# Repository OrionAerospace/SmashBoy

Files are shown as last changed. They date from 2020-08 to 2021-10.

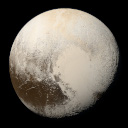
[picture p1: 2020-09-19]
Telemetria/Software/RPi/pluto128.jpg

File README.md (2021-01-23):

# SmashBoy

[Lista de componentes](https://docs.google.com/spreadsheets/d/1D1GIcy4P2cfkP9AKwlNsk9UkS25Sl03CtQvyfefxdTE/edit#gid=0)

[Posição Pinos Conector](https://docs.google.com/spreadsheets/d/1PznWzXu9q9Dlj_FaWwlBaMU61vmlcZUDXJRLBAa3UJ4/edit#gid=0)

LAYERS SMASHBOY

(9) --> 

(8) --> Controle

(7) --> 

(6) --> Atuadores Controle

(5) -->

(4) --> Bateria  (ok)

(3) --> Controlador bateria  (ok)

(2) --> Transceiver  (ok)

(1) --> Câmera + OBC & PYLD Ctrl  (ok)

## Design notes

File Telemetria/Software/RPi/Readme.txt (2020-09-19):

19/09/2020

Transferencia de arquivos por SPI com CRC32 e cabeçalho foi implementada
Falta ainda implementar a lógica com UART e o tratamento de erros

O ARQUIVO DEVE SER COMPILADO COM PYTHON 3

-------------------------------------

16/09/2020

Criada a pasta RPi, aqui estará todo o código para o Raspberry.

Em maio eu havia escrito um código em C, mas como a câmera funciona com um código em Python, então acho que não haverá uma mudança
 significativa de desempenho se todo o algoritmo do raspberry for em Python. Além disso, em Python fica mais simples para ser lido
 pelas próximas pessoas que estarão fazendo parte da equipe.

--------------------------------------

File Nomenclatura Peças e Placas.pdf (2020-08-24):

# Padronização Nomenclatura Peças e Placas

## Description

Padronizar o nome e caminho para fácil localização e entendimento.

PADRÃO NOMENCLATURA (EX):

SMASHBOY_AVI_ACI_ASS01_PART01_V01

Leitura: Projeto SmashBoy, Área da Aviônica, Equipe de Acionamentos e Estrutura, Montagem de Peças, Peça 01, Versão 01.

Sendo os espaçamentos (em ordem):

1. Nome do projeto.
2. Área.
3. Equipe.
4. Montagem de peças ou placas.
5. Peça ou Placa.
6. Versão.

OBS:

- O espaçamento 3 pode ser preenchido com os respectivos códigos: ACI (acionamento e estrutura), ENE (energia), CON (controle), TEL (telemetria).
- Para CAD em SolidWorks o espaçamento 4 = ASS (assembly).
- Para CAD em Altium o espaçamento 4 = PCB (printed circuit board).
- Para casos que tenham integração Altium + SolidWorks, espaçamento 4 = INT (integração).

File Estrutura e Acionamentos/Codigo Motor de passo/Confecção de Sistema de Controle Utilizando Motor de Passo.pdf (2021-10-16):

Confecção de Sistema de Controle Utilizando Motor de Passo

Para o desenvolvimento do projeto, o qual tem como objetivo se mover em linha reta com velocidade constante de 5 cm/s, será utilizado motor de passo e sensor de fim de curso.

Materiais Utilizados

- 1 Esp 32 ou Arduíno;
- 2 Chaves Fim de Curso;
- 1 Motor de Passo;
- 2 Led’s (verde e azul);
- Fonte de alimentação 9V - 500mA;
- 2 Resistores (150Ω);
- 1 Capacitor eletrolítico (100µF);
- Driver Motor de Passo A4988;

Código

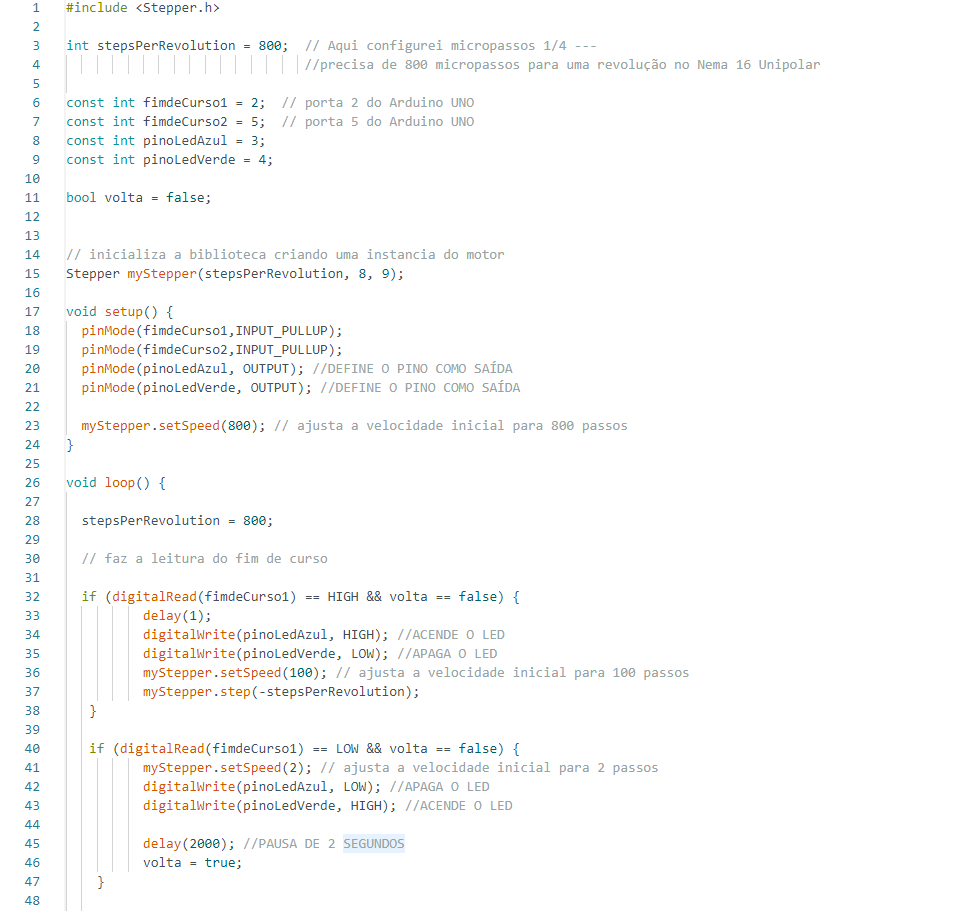
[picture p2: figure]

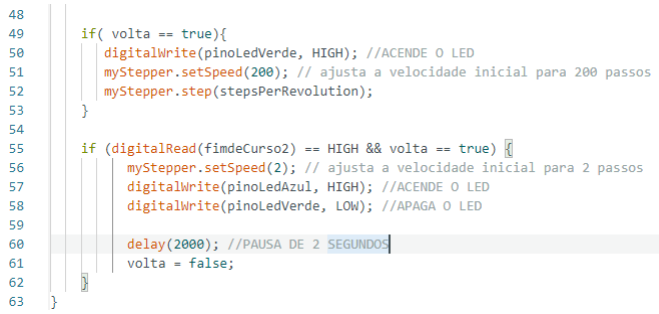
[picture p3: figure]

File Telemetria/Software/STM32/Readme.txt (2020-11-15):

11/2020

Todo o sistema passou por uma grande mudança, todo o código foi reescrito e toda sua lógica reformulada.

'Fluxograma RTOS V3' trás uma reestruturação das tasks, onde agora apenas uma única task pode acessar o 
 módulo de rádio, isso reduziu drasticamente a complexidade além da redução de memória e probabilidade
 de falhas/erros.
 
Outra grande mudança foi a lógica de "Maquina de estados" que simplificou drasticamente a programação e
 tornou o código mais simples de entender e mais seguro.

-----------------------------------------------------------
09/2020

[DESATUALIZADO] SmashBoy - FreeRTOS - Funcionamento Superficial Software [DESATUALIZADO] 
https://docs.google.com/spreadsheets/d/1H0UxWHC4-2a8tMSLyNS2wVXkgVRTFNAkbJkslC1BT0Q/edit#gid=0

[DESATUALIZADO][DESATUALIZADO]
O fluxograma RTOS V1 descreve a maneira como o sistema operacional do CubeSat irá se comportar, cada Task 
 pode ser compreendida como um conjunto de instruções que funciona em seu próprio loop de trabalho, 
 algumas tasks possuem dependências com outras.

[DESATUALIZADO] [DESATUALIZADO] [DESATUALIZADO] 
O rádio se encontrará na maior parte do tempo em RX mode, assim que uma nova mensagem chegar, será 
 encaminhada para a Task 0 (que estará ativa durante todo o tempo) esta task é responsável por fazer 
 uma triagem da informação e ativar a task que corresponde à tarefa, além disso, assim que uma mensagem 
 for recebida com sucesso, um ACK será emitido, informando para a base que o CubeSat recebeu o comando 
 com sucesso. A task 1 é responsável por concentrar toda a informação e envia-la ao transmissor 
 periodicamente. A task 2 é responsável por realizar o envio da imagem e é a única que não depende da 
 task 1 para o envio dos dados, a imagem será enviada assim que o comando for recebido. As demais tasks 
 são autoexplicativas.
 [DESATUALIZADO] [DESATUALIZADO] [DESATUALIZADO]

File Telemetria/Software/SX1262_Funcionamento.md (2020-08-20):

# SX1262

---------------------------

### Notas sobre o funcionamento do SX1262 e SX1280.

Henrique Terzi Lucchetta, 20/08/2020.

----------------------------

Este CI não necessita de biblioteca, pois o mesmo já implementa uma sequência de funcionamento semelhante ao uso de uma. É fundamental monitorar o pino BUSY, pois com base no nivel lógico deste pino que será possível determinar quando o CI está apto para receber um novo comando, caso este pino não seja monitorado, ocorrerão falhas inesperadas de funcionamento.

A interpretação do datasheet é confusa num primeiro momento, diferentemente de sua versão anterior (SX1272) este CI não fornece a tabela completa de registradores, então sua configuração e uso acontece por meio de "funções" baseadas em OpCode.

A seção 14 do datasheet explica a sequência de funcionamento para uma transmissão e para a recepção. Cada item descrito na seção 14 tem seu funcionamento descrito na seção 13, cada função da seção 13 possui um OpCode, esse OpCode é sempre o primeiro byte que vai informar para o CI o que os dados seguintes representam, exemplo:

**SetStandby**, coloca o CI em Standby e define qual o oscilador interno será utilizado durante este modo (RC ou XTAL), a mensagem que será transmitida deve primeiramente verificar se o pino BUSY está em LOW, caso esteja em HIGH aguarde passar para LOW, em seguida o pino SPI NSS deve ir para LOW para o SX1262 receber o comando, depois deve enviar o OpCode correspondente a SetStandby (no caso, 0x80) e o próximo byte correspondente ao oscilador utilizado (StdbyConfig), neste caso pode ser (0x00 ou 0x01), a mensagem completa enviada via SPI será então **0x80 0x00** ou **0x80 0x01**.

Read/WriteRegister e Read/WriteBuffer, também possuem OpCodes, endereços e offsets que devem ser enviados antes do valor a ser lido ou inserido nos registradores, exemplo WriteRegister:

 > BUSY == LOW
 
 > NSS = LOW
 
 > SPI_WRITE = **0x0D 0x07 0x40 0x34 0x44**
 
 > NSS = HIGH
 
 No caso da mensagem acima, foi atribuido no registrador 0x0740 o valor 0x34 e no 0x0741 o valor 0x44, a cada novo byte o endereço seguinte é automaticamente definido.
 
 **Além de aguardar o pino BUSY, é necessário tbm aguardar um breve periodo de tempo para enviar o próximo comando, este tempo é especificado no datasheet**

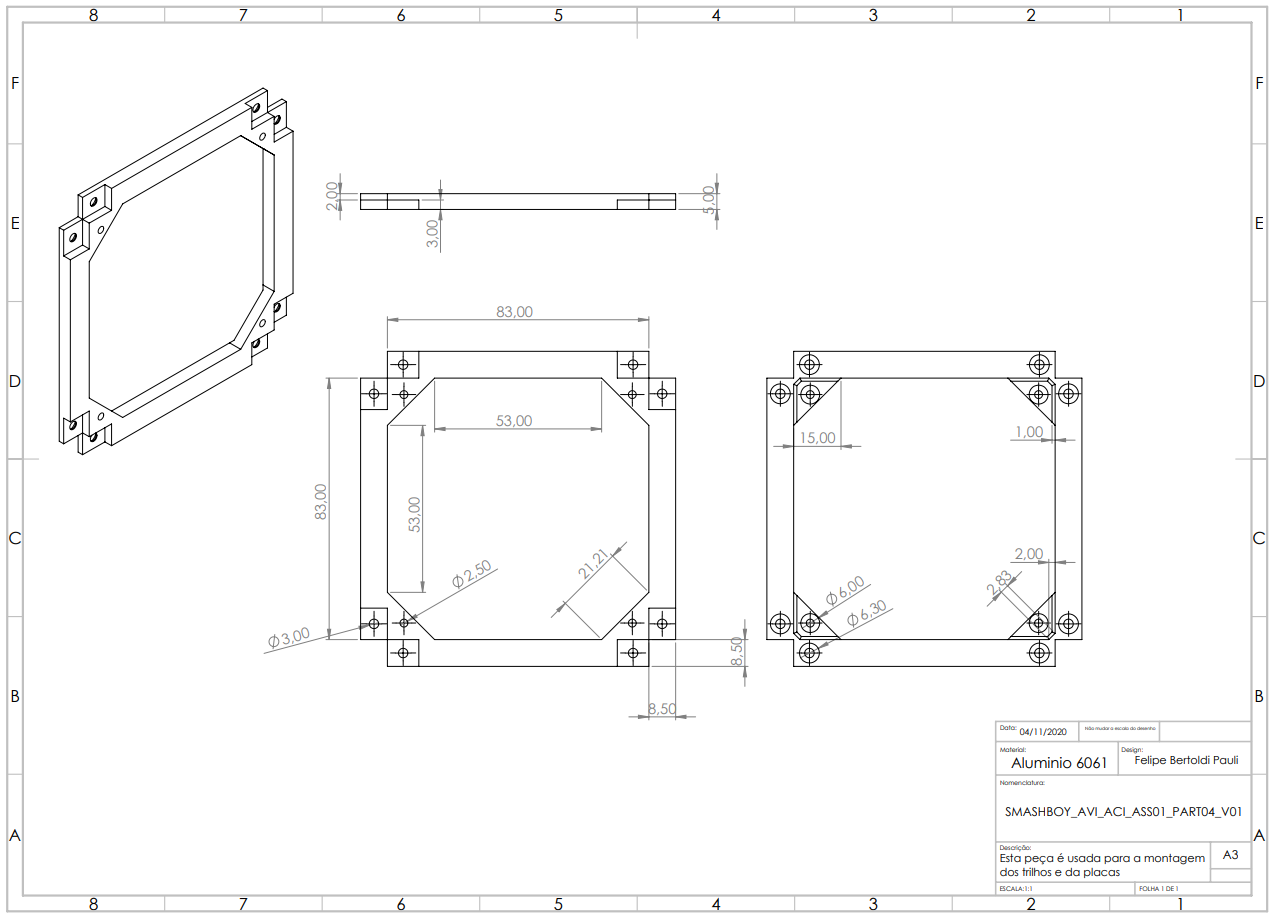
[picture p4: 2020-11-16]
Estrutura e Acionamentos/peça esqueleto/Capturar.PNG

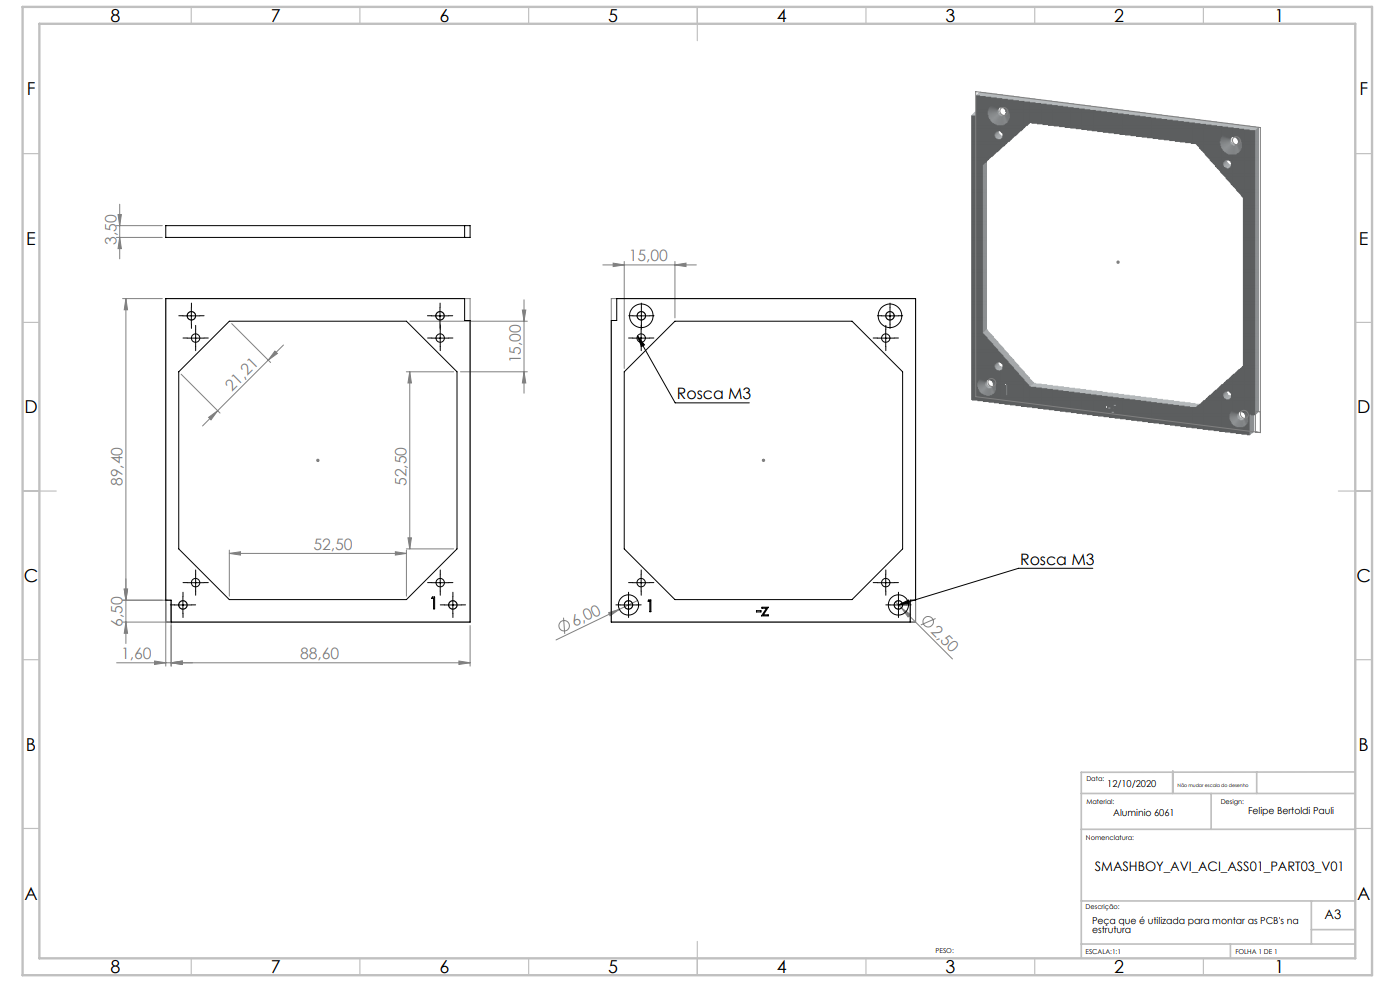
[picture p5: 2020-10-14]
Estrutura e Acionamentos/Fixação das placas/Capturar.PNG

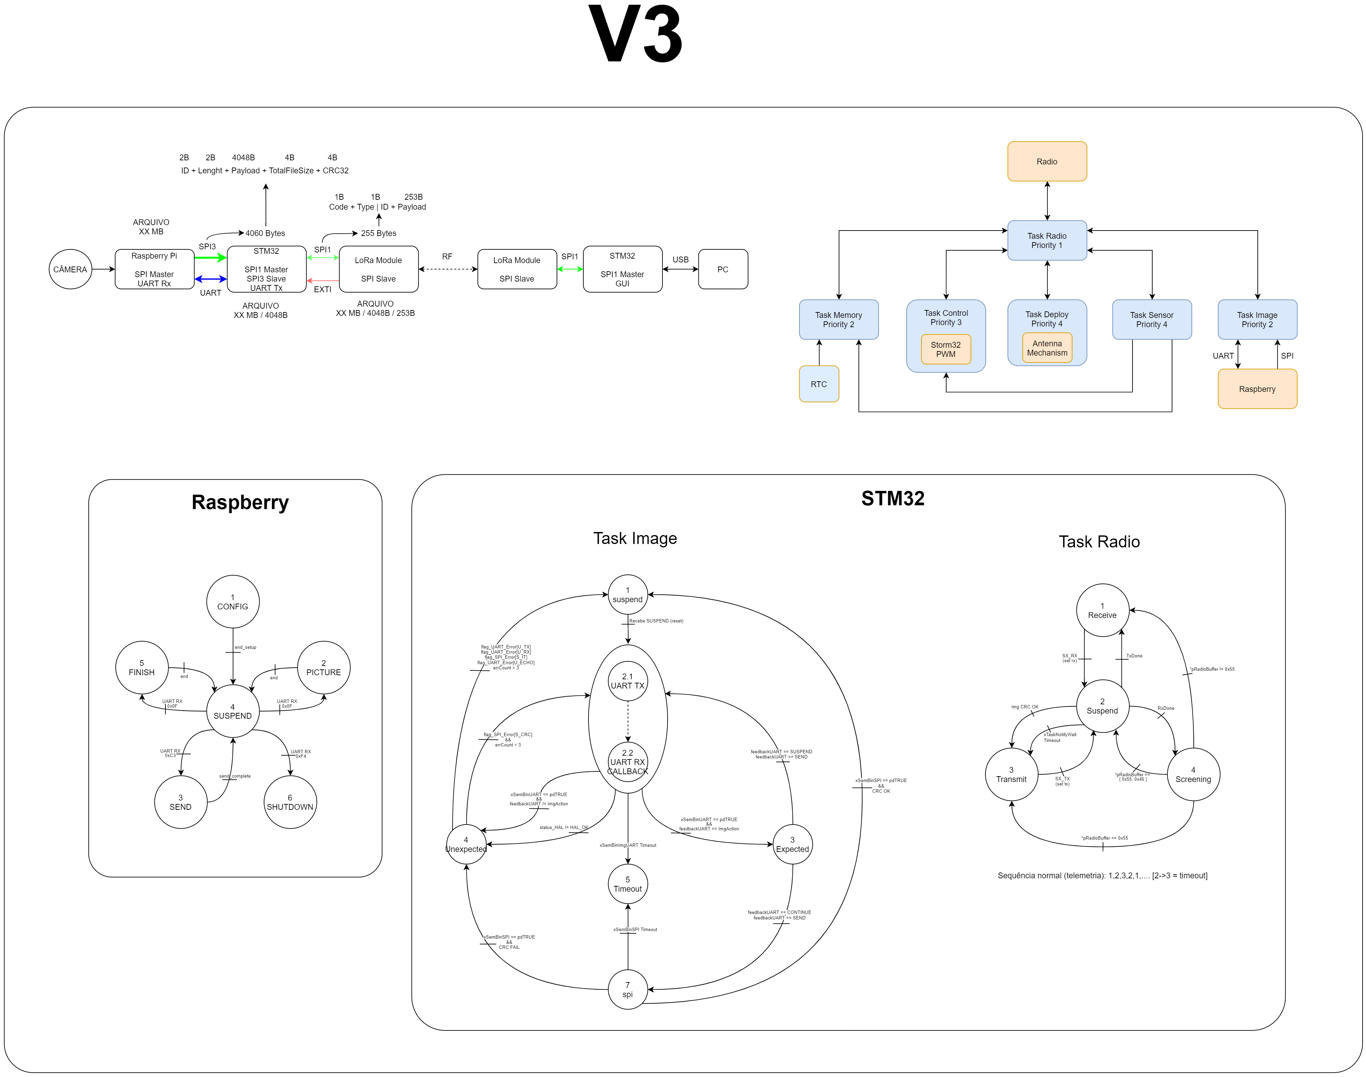
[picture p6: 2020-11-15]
Telemetria/Software/STM32/Software_SmashBoy_V3.png

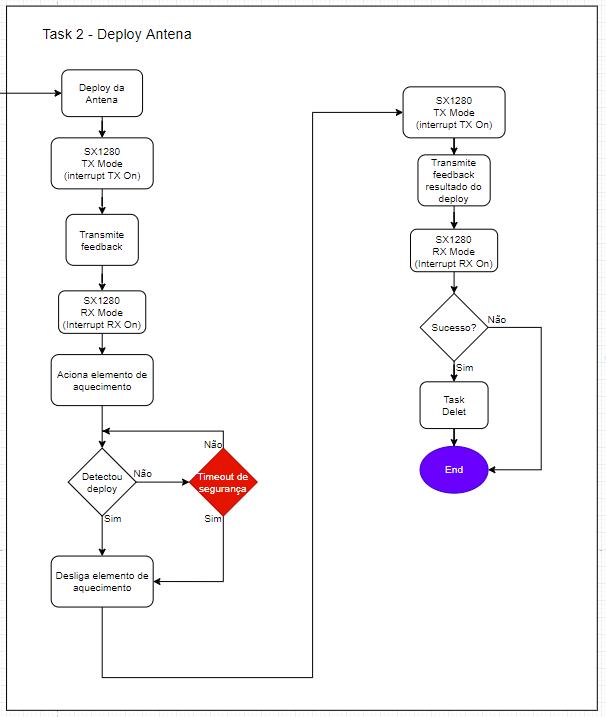
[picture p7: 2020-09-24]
Telemetria/Software/STM32/fluxograma RTOS - Deploy [ DESATUALIZADO ].png

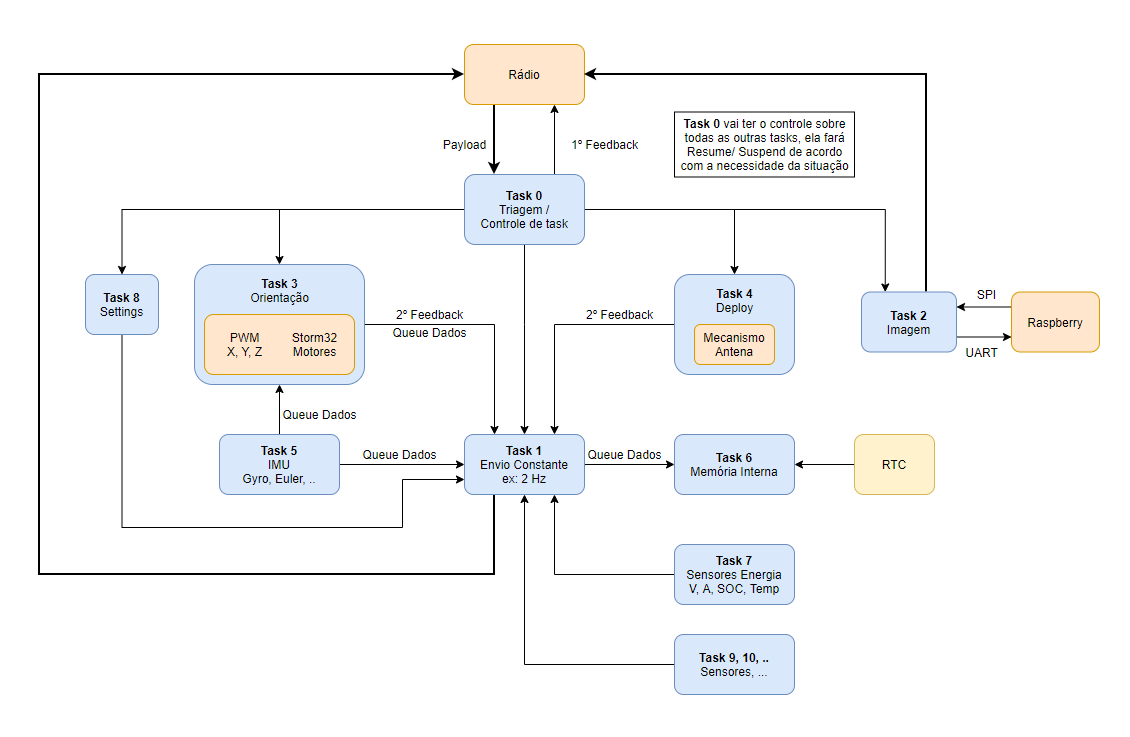
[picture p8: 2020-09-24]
Telemetria/Software/STM32/fluxograma RTOS V1.png

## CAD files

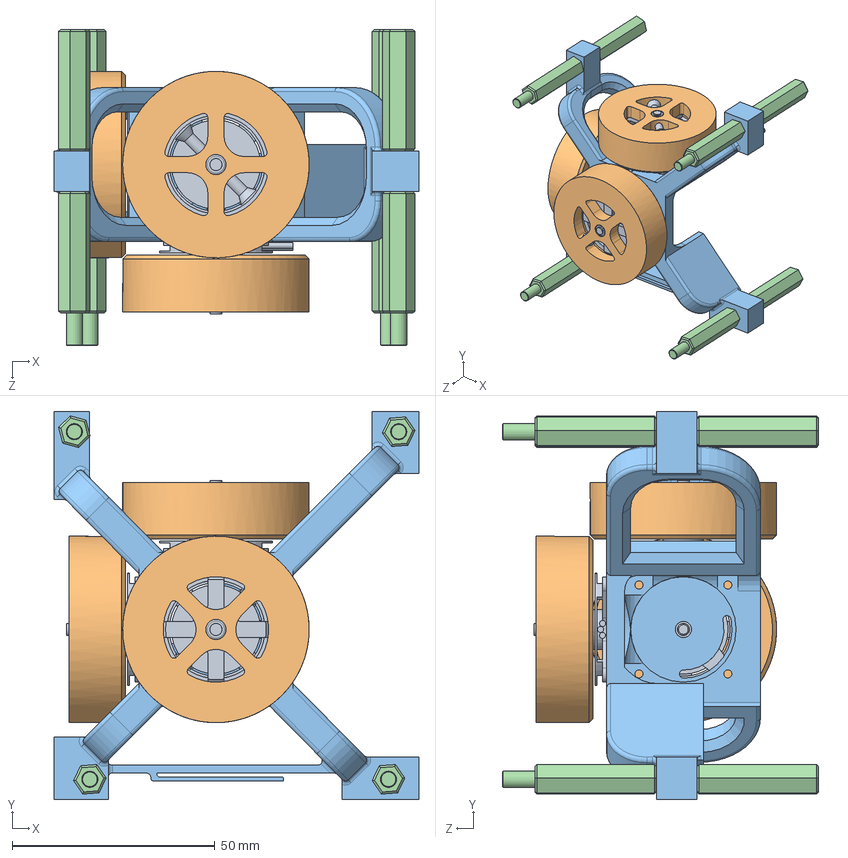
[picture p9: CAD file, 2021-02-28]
Estrutura e Acionamentos/Roda de reação/Roda_reação.SLDASM
90.0 x 95.7 x 78.0 mm
LE2204 kv1800 x 3
roda de reação x 3
suporte
Espaçador-30mm (971300474) x 8

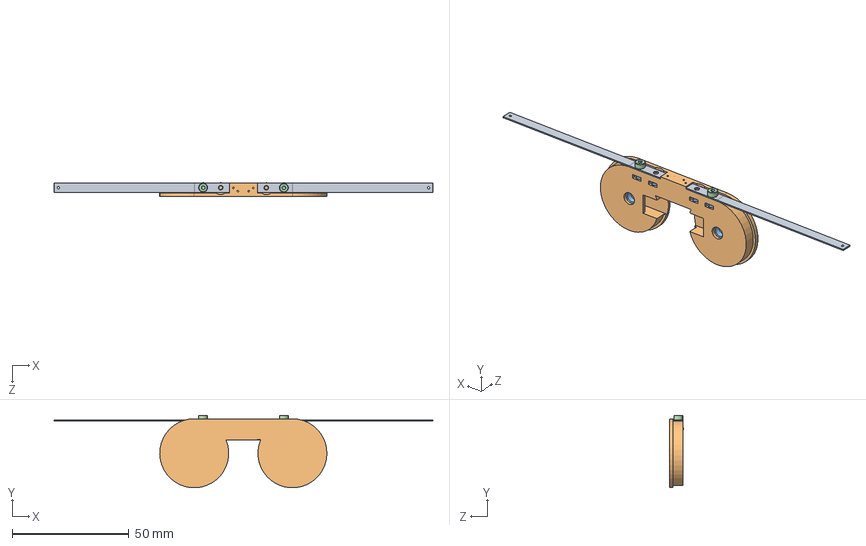
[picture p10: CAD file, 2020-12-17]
Estrutura e Acionamentos/base deploy/dedede.SLDASM
162.1 x 31.0 x 6.19 mm
antena_01 x 2
base deploy^dedede
hex thin nut chamfered gradeab_din x 6
socket head cap screw 4762_din x 2

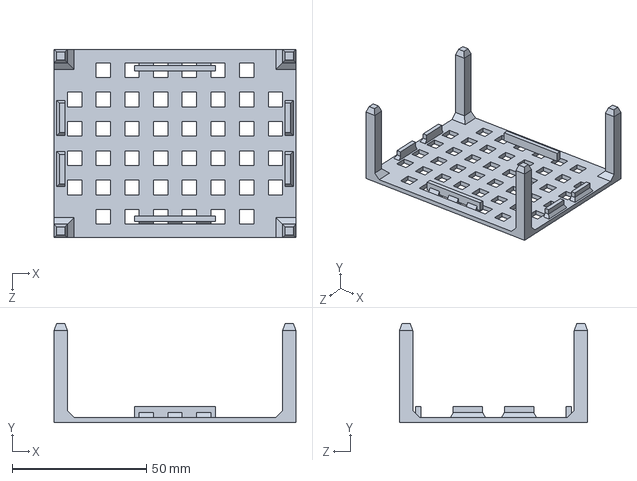
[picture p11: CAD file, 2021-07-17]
ADCS/SETUP_ADCS/antigo/L1.SLDPRT
90.0 x 37.0 x 70.0 mm

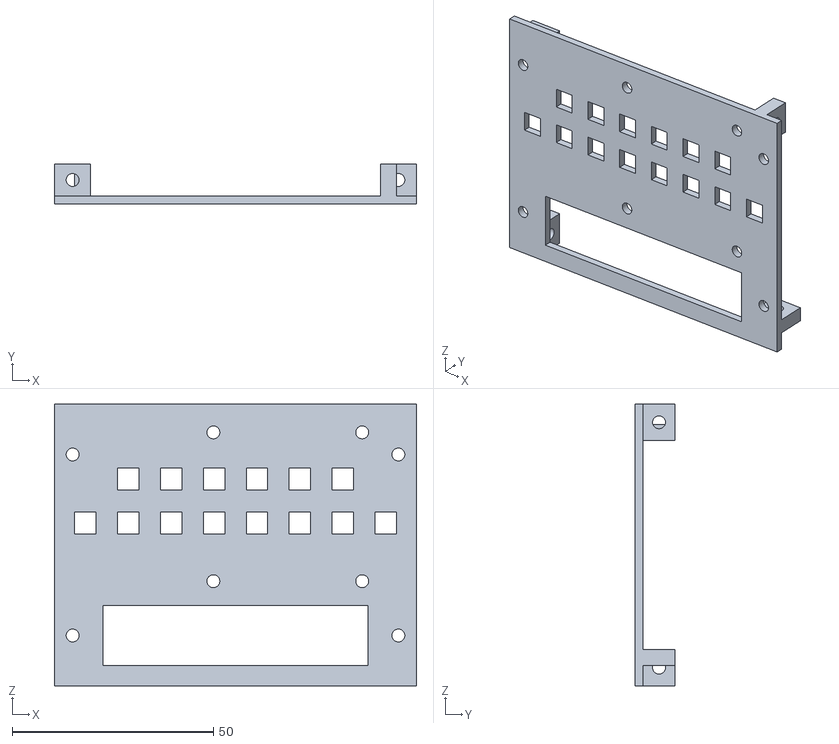
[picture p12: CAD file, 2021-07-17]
ADCS/SETUP_ADCS/STL/L2_v2.STL
90.0 x 10.0 x 70.0

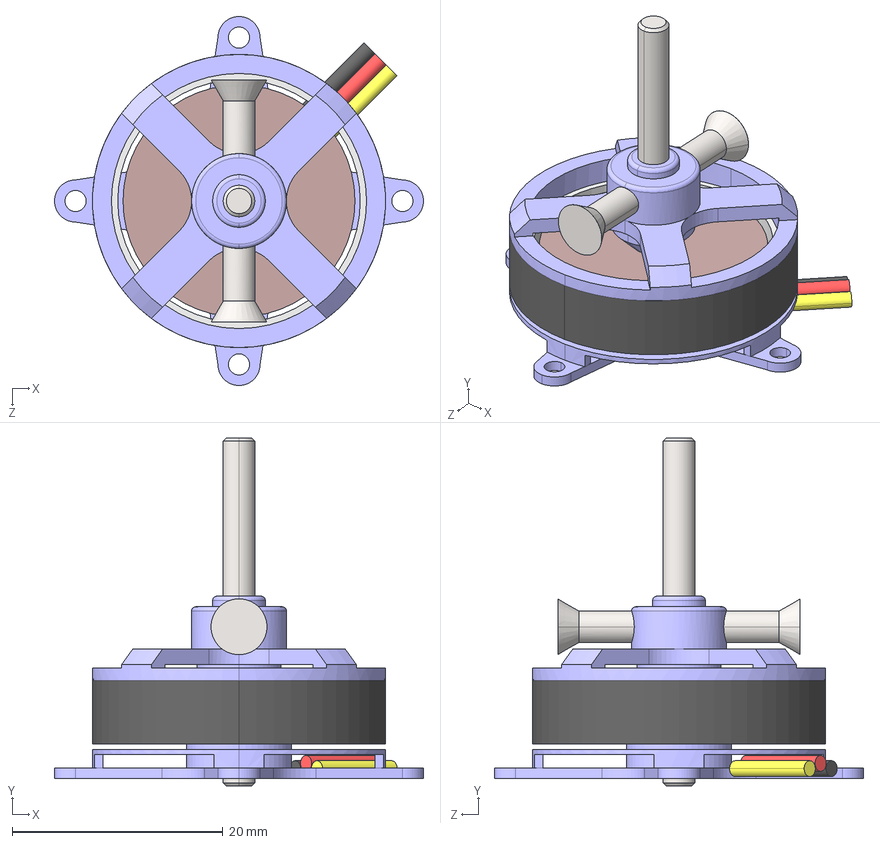
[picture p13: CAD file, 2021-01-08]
Controle/Motor_BLDC_LE2204_KV1800.STEP
35.0 x 33.0 x 35.0 mm

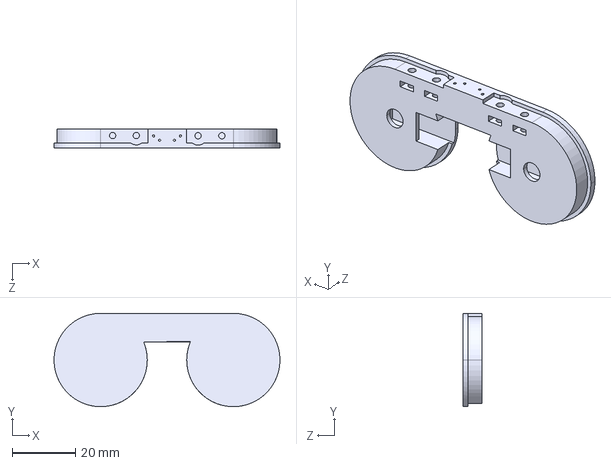
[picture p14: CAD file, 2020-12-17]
Estrutura e Acionamentos/base deploy/SMASHBOY_AVI_ACI_ASS01_PART05_V01..STEP
71.5 x 29.5 x 5.90 mm

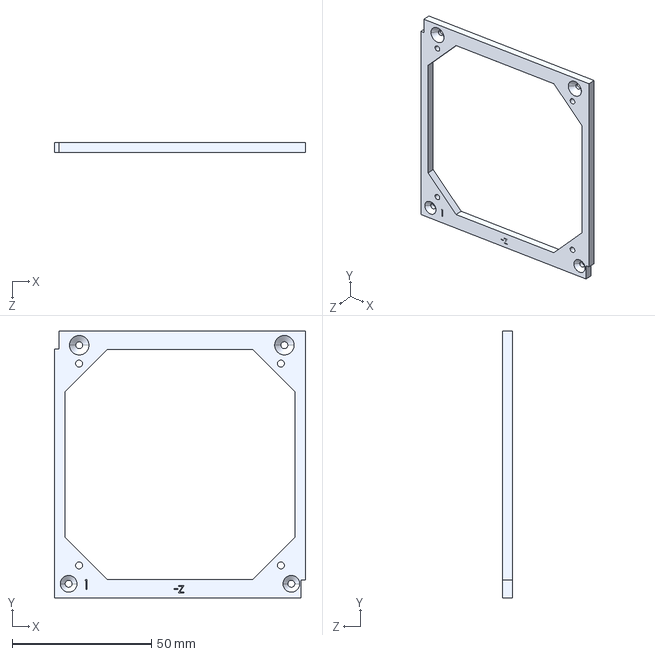
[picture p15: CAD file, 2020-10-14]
Estrutura e Acionamentos/Fixação das placas/fixação placas -face -z.STEP
90.2 x 95.9 x 3.50 mm

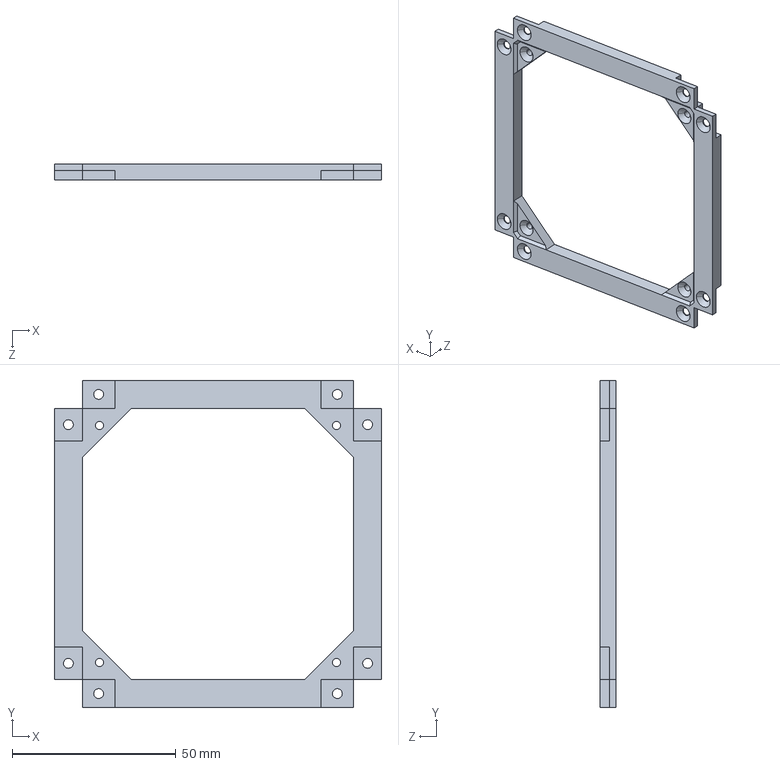
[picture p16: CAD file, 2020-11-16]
Estrutura e Acionamentos/peça esqueleto/peça esqueleto-v2.STEP
100.0 x 100.0 x 5.00 mm

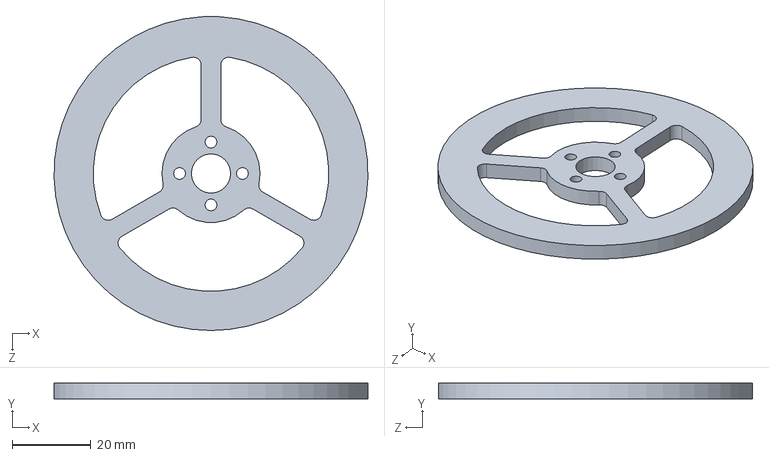
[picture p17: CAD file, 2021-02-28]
Estrutura e Acionamentos/Roda de reação/[3D]_SMASHBOY_Layers_Motor_Disco/Peça2.SLDPRT
80.0 x 4.00 x 80.0 mm

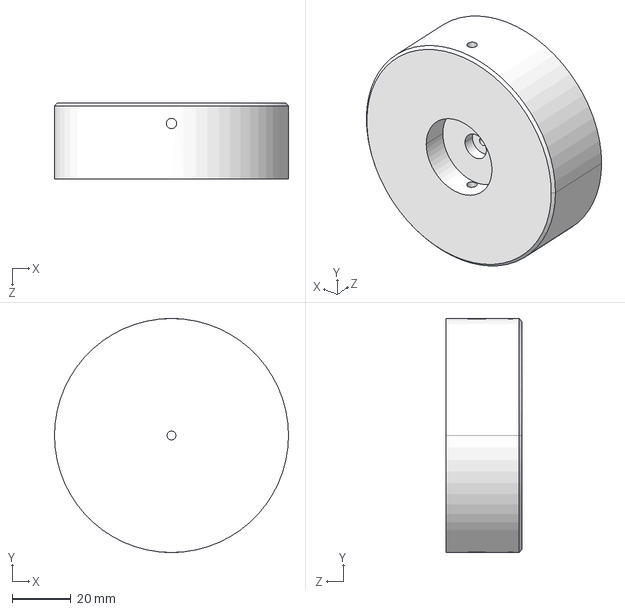
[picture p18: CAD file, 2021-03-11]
Estrutura e Acionamentos/Roda de reação/massa/roda de reação_nylon.STEP
80.0 x 80.0 x 26.0 mm

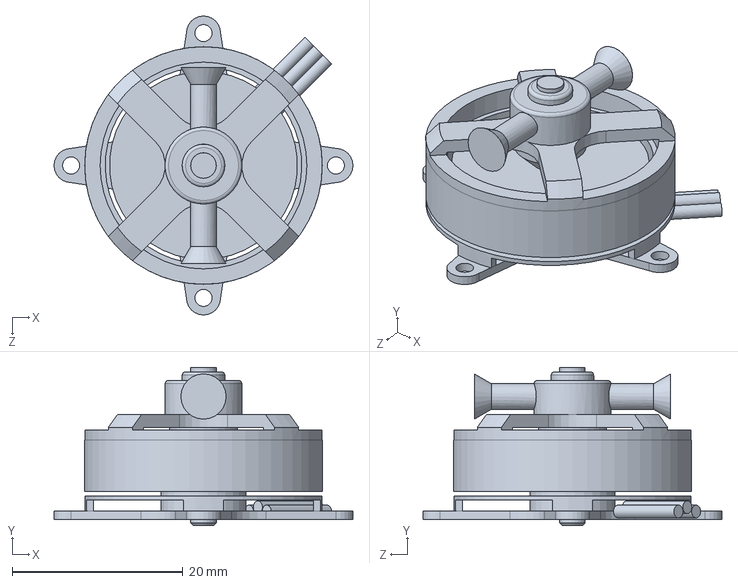
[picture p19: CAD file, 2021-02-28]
Estrutura e Acionamentos/Roda de reação/motor/LE2204 kv1800.SLDPRT
35.0 x 18.5 x 35.0 mm

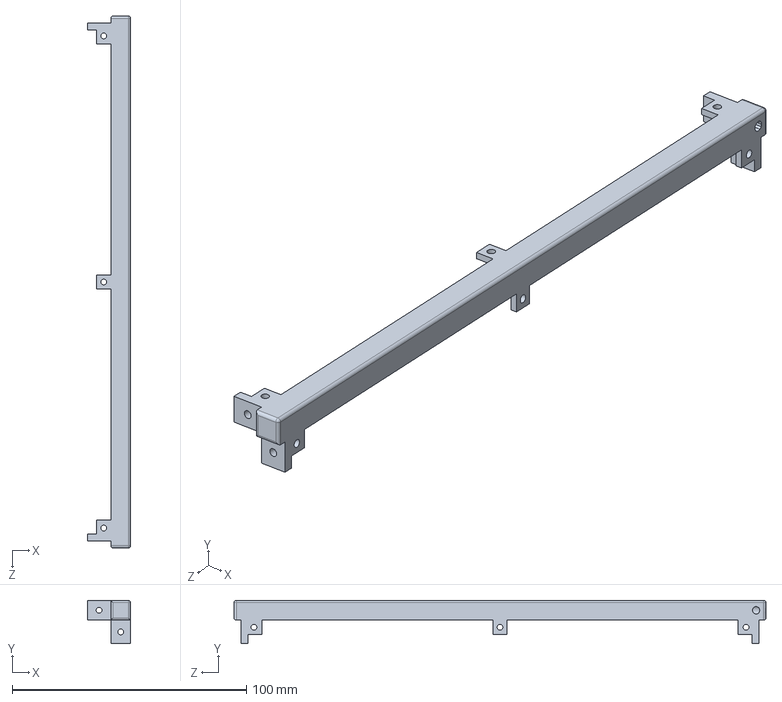
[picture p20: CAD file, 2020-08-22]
Estrutura e Acionamentos/trilhos/trilho-separation-spring.SLDPRT
18.5 x 18.5 x 227.0 mm

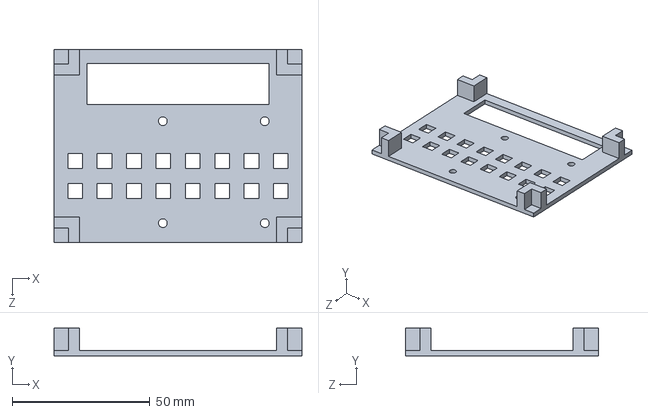
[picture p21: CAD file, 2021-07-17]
ADCS/SETUP_ADCS/antigo/L2.SLDPRT
90.0 x 10.0 x 70.0 mm

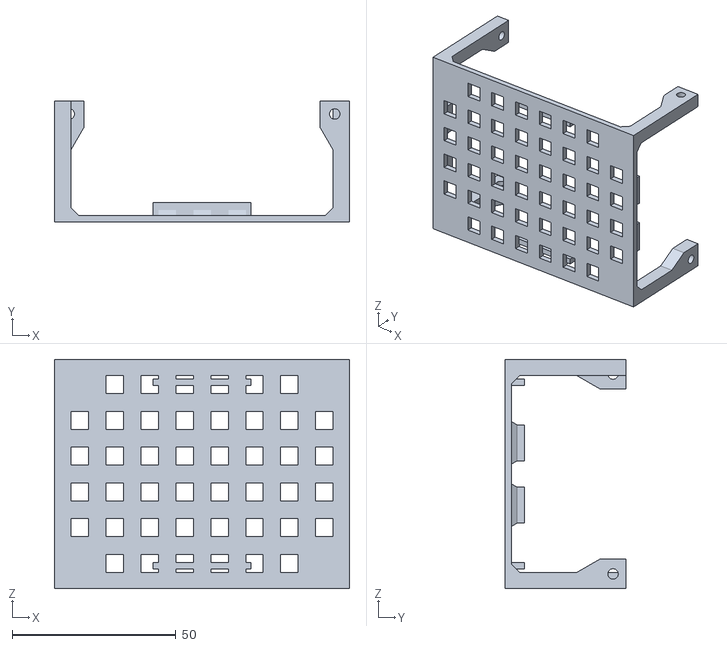
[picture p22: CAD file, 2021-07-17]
ADCS/SETUP_ADCS/STL/L1_v2.STL
90.0 x 37.0 x 70.0

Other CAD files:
Estrutura e Acionamentos/Fixação das placas/fixação placas.SLDPRT
Estrutura e Acionamentos/Roda de reação/[3D]_SMASHBOY_Layers_Motor_Disco/Disco_Inercia.SLDPRT
Estrutura e Acionamentos/Roda de reação/massa/roda de reação.STEP
Estrutura e Acionamentos/Roda de reação/suporte.SLDPRT
ADCS/SETUP_ADCS/STL/L2_A_v2.STL
ADCS/SETUP_ADCS/STL/L3_v2.STL
ADCS/SETUP_ADCS/STL/suporte_M.STL
ADCS/SETUP_ADCS/antigo/L2_A.SLDPRT
ADCS/SETUP_ADCS/antigo/L3.SLDPRT
Estrutura e Acionamentos/Fixação das placas/fixação placas -face -z.SLDDRW
Estrutura e Acionamentos/Fixação das placas/fixação placas -face -z.SLDPRT
Estrutura e Acionamentos/Roda de reação/[3D]_SMASHBOY_Layers_Motor_Disco/Disco_Inercia.x_t
Estrutura e Acionamentos/Roda de reação/[3D]_SMASHBOY_Layers_Motor_Disco/LE2204 kv1800.x_t
Estrutura e Acionamentos/Roda de reação/massa/roda de reação.SLDDRW
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

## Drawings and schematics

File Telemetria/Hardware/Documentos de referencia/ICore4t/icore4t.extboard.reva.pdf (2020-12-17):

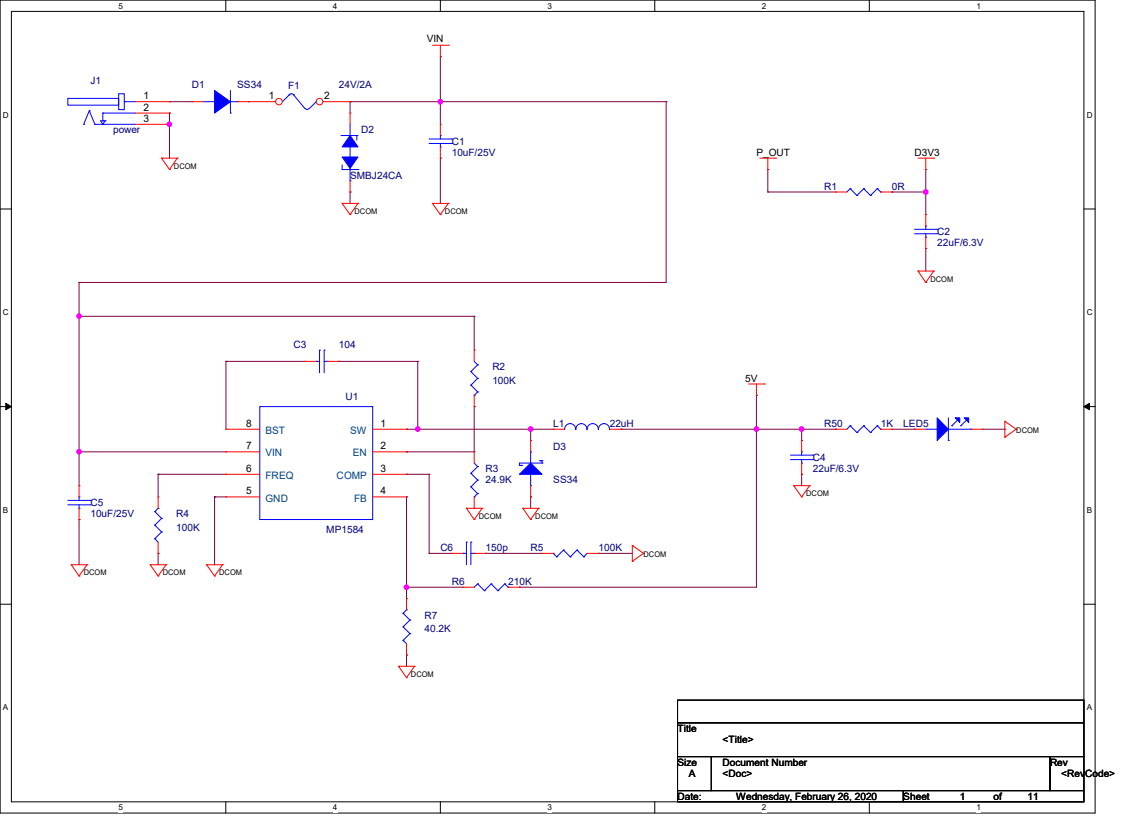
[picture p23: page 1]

VIN

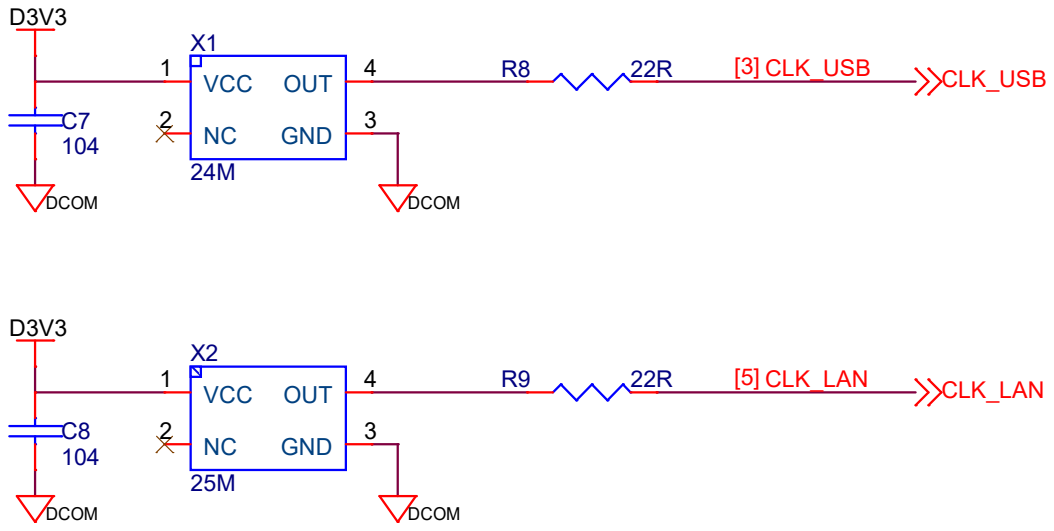
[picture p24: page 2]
CLK_USB; CLK_LAN; D3V3DCOM; DCOM; CLK_USB [3]; CLK_LAN [5]; Title; <Title>; Wednesday, February 26, 2020; VCC 1; GND 3; OUT 4

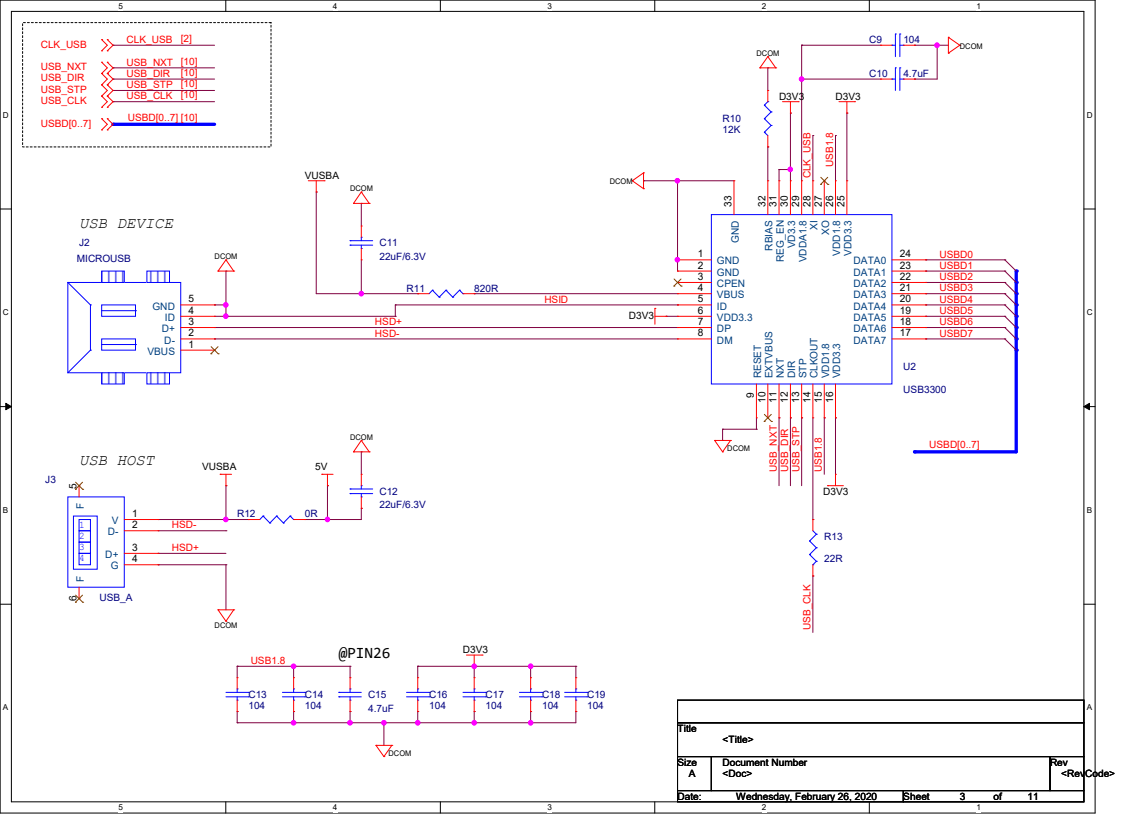
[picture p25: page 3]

9 EXTVBUS 10 NXT 11 DIR 12 STP 13 CLKOUT 14 VDD1.8 15 VDD3.3 16 RBIAS 32 REG_EN 31 VD3.3 30 VDDA1.8 29 XI 28 XO 27 VDD1.8 26 VDD3.3 25

## USB DEVICE

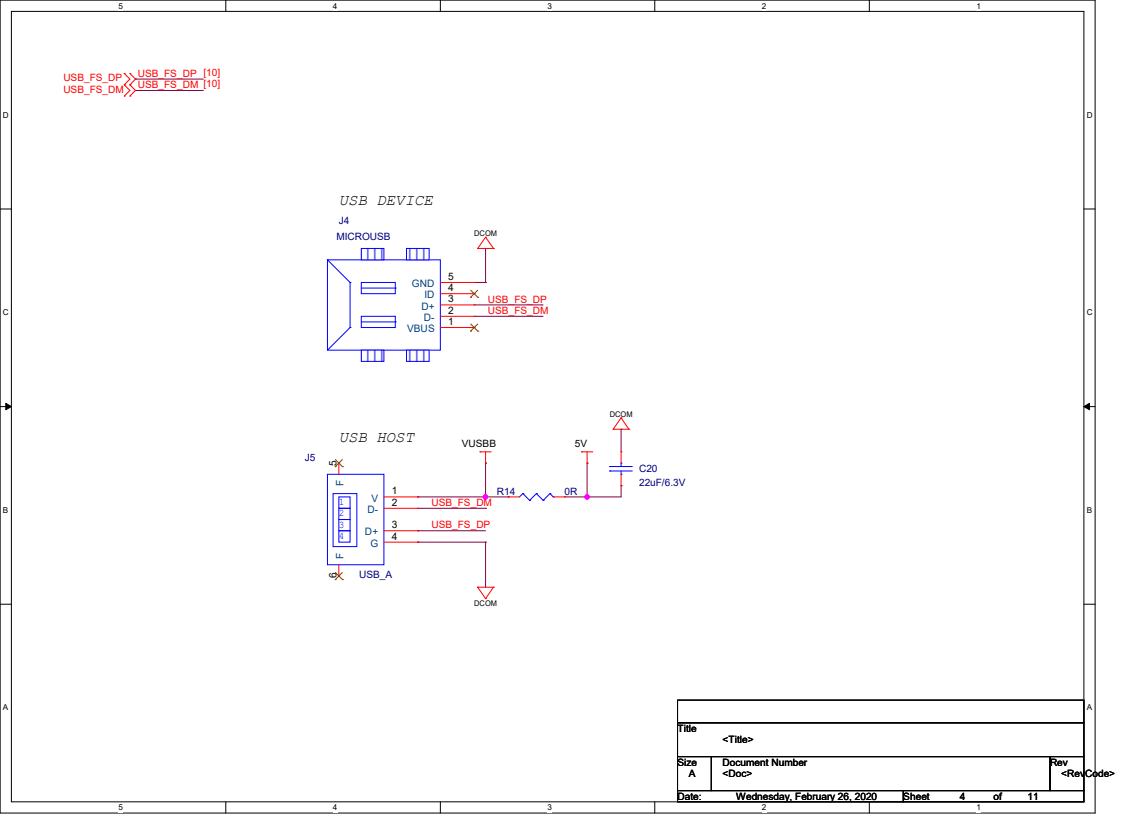
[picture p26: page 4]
USB HOST; USB_FS_DM; USB_FS_DP; USB_FS_DP USB_FS_DM; DCOM; VUSBB; 5V DCOM; Title; <Title>; Wednesday, February 26, 2020; USB_A; J4 MICROUSB; VBUS 1 D- 2 D+ 3; ID 4 GND 5

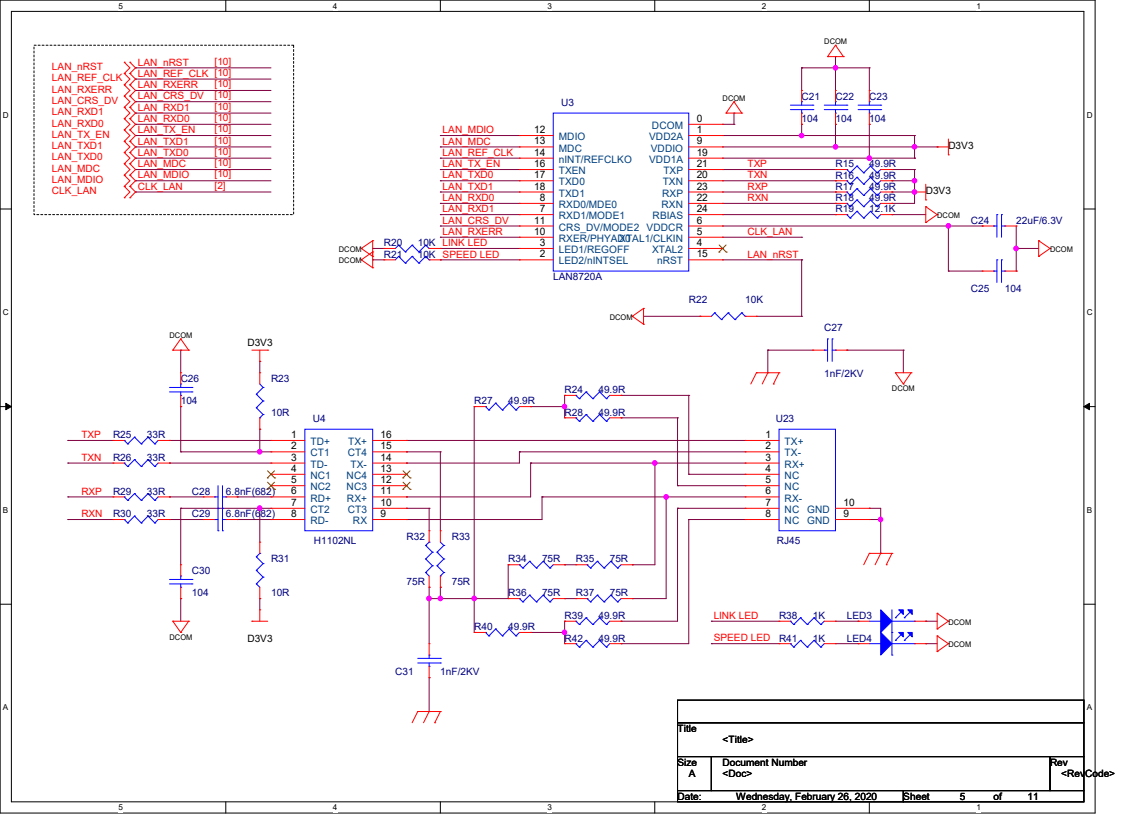
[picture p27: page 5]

# D3V3DCOM

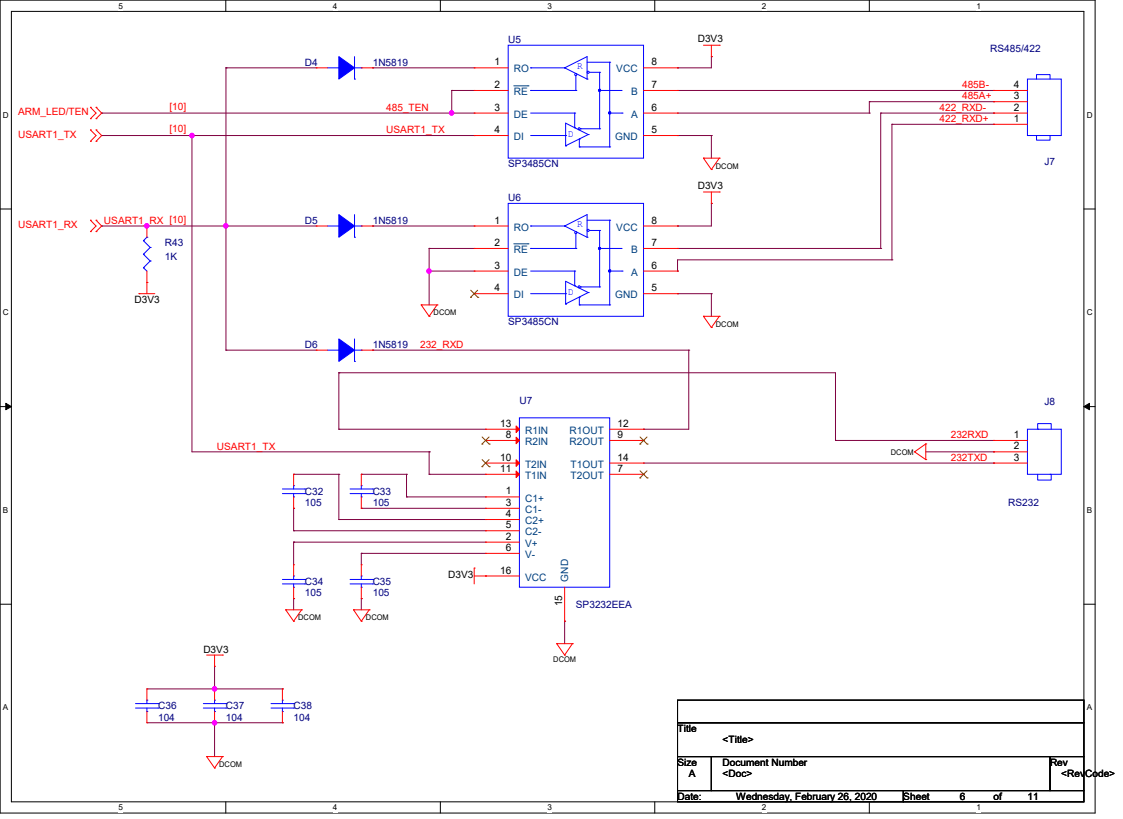
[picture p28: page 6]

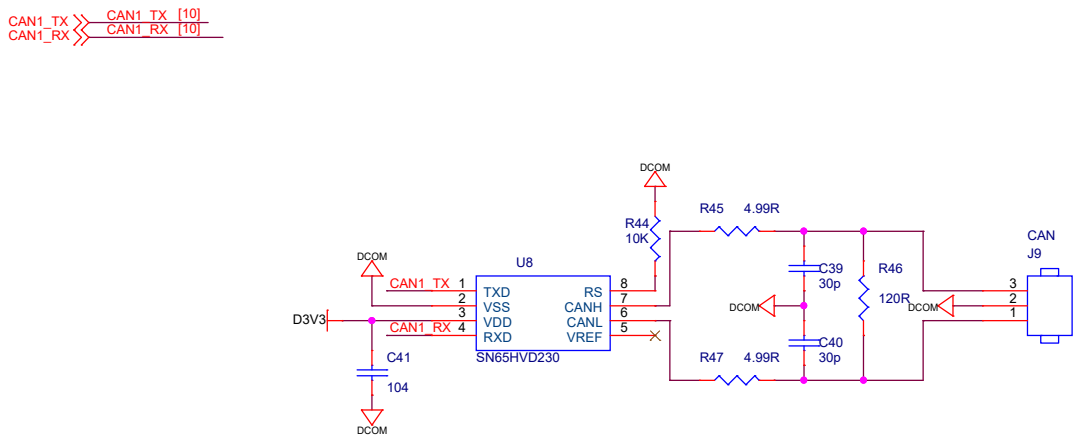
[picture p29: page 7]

# 5V DCOM

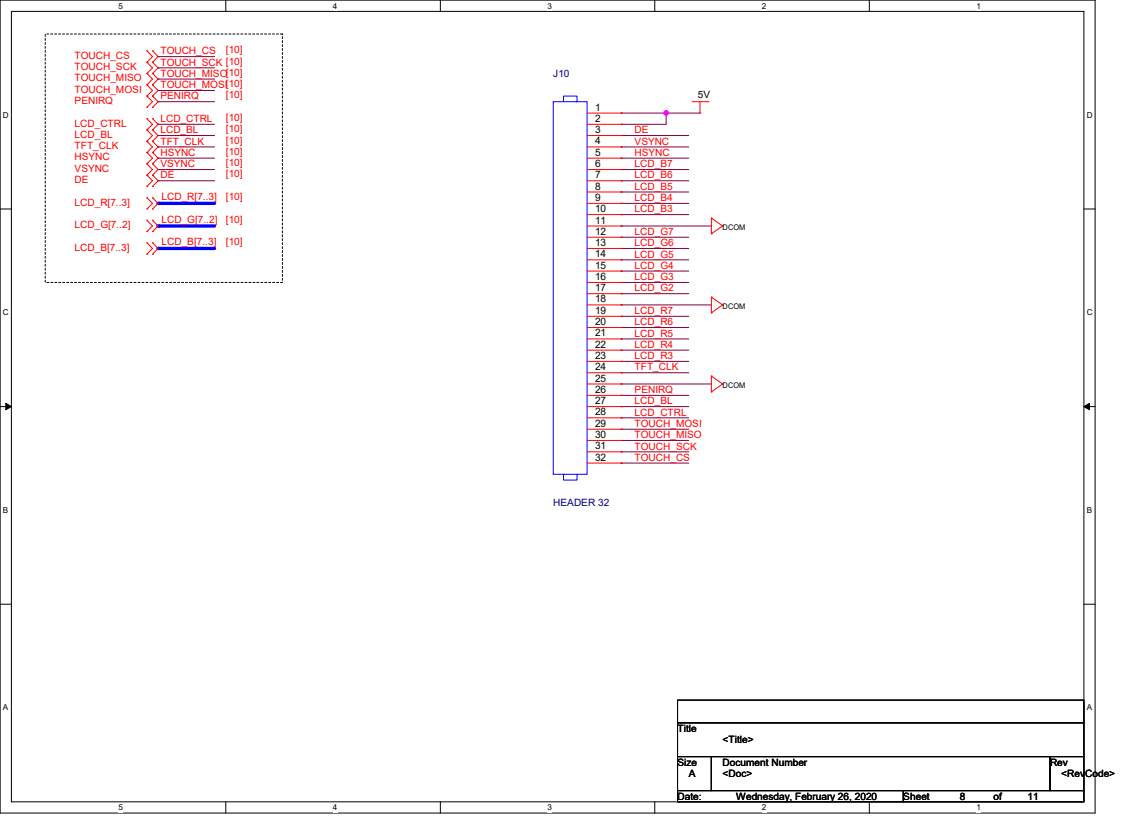
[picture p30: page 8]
TOUCH_CS TOUCH_SCK; TOUCH_MISO; VSYNC; TOUCH_MOSI; HSYNC; PENIRQ; LCD_B7 LCD_B6 LCD_B5 LCD_B4 LCD_B3; LCD_G7 LCD_G6; LCD_CTRL; LCD_G5; LCD_BL; LCD_G4; TFT_CLK; LCD_G3; LCD_G2; VSYNC DE; LCD_R7 LCD_R6; LCD_R[7..3]; LCD_R5 LCD_R4; LCD_G[7..2]; LCD_R3 TFT_CLK; LCD_B[7..3]; PENIRQ LCD_BL LCD_CTRL TOUCH_MOSI TOUCH_MISO TOUCH_SCK TOUCH_CS; DCOM; TOUCH_CS; TOUCH_SCK; Title; <Title>; Wednesday, February 26, 2020; HEADER 32

MSDA/R3 | [11] MSCL/T2 | [11] T3 | [11] P6 | [11] R4 | [11] T4 | [11] N3 | [11] P3 | [11] N5 | [11] N6 | [11] N8 | [11] P8 | [11] R5 | [11] R6 | [11] R7 | [11] R8 | [11] | L10 | [11] L11 | [11] M11 | [11] M9 | [11] N12 | [11] N9 | [11] P14 | [11] P9 | [11] R10 | [11] R11 | [11] R12 | [11] MSDA/R13 | [11] MSCL/R14 | [11] R9 | [11] T10 | [11] T11 | [11] T12 | [11] T13 | [11] T14 | [11] T15 | [11] T9 | [11] M10 | [11] N11 | [11] P11 | [11] MSDA/E11 | [11] MSCL/E10 | [11] A14 | [11] B14 | [11] A10 | [11] B10 | [11] B9 | [11] C14 | [11] C9 | [11] D11 | [11] D12 | [11] D14 | [11] D9 | [11] E9 | [11] F10 | [11] F11 | [11] F9 | [11] C11 | [11] B11 | [11] B12 | [11] B13 | [11] A11 | [11] A12 | [11] A13 | [11] A15 | [11] A9 | [11] A7 | [11] B8 | [11] C8 | [11] D8 | [11] E8 | [11] F8 | [11] B16 | [11] C16 | [11] D16 | [11] F16 | [11]

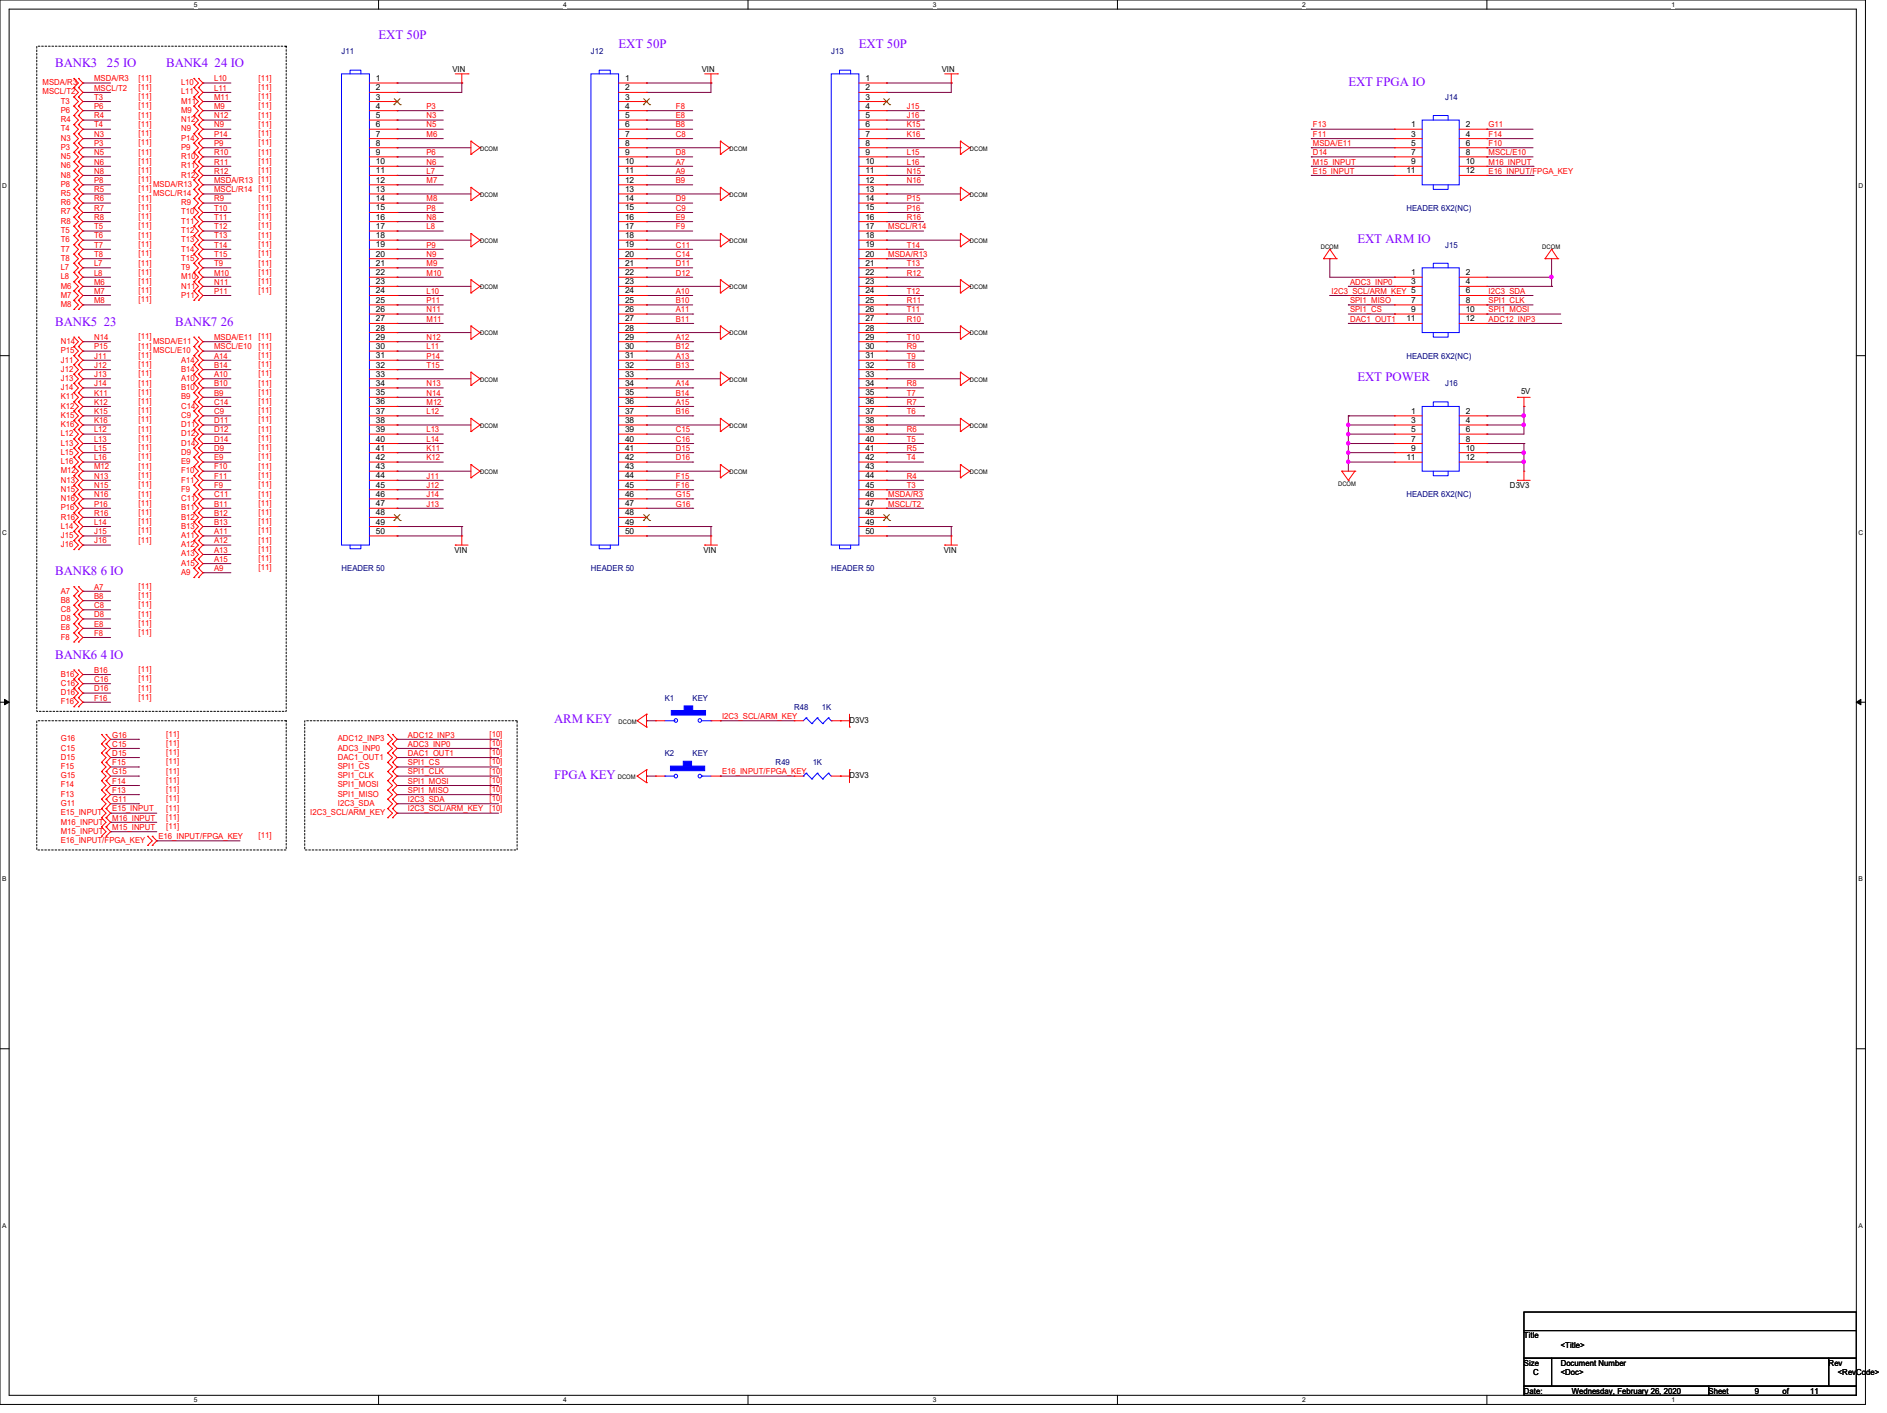
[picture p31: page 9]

# USB

HS

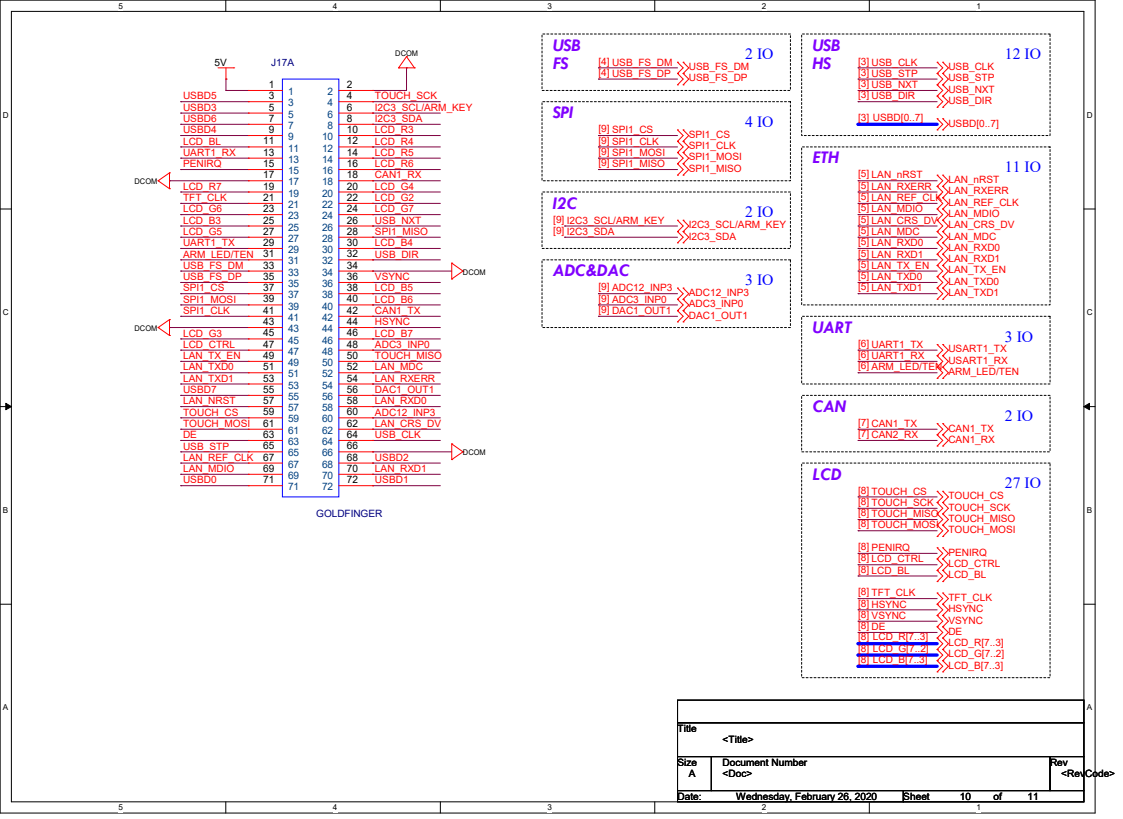
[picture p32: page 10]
ETH; UART; CAN; LCD; USB; SPI; 3 IO ADC&DAC; USBD5; TOUCH_SCK; USBD3; I2C3_SCL/ARM_KEY; USBD6; I2C3_SDA; USBD4; LCD_R3; LCD_BL; LCD_R4; UART1_RX; LCD_R5; PENIRQ; LCD_R6; CAN1_RX; LCD_R7; LCD_G4; TFT_CLK; LCD_G2; LCD_G6; LCD_G7; LCD_B3; USB_NXT; LCD_G5; SPI1_MISO; UART1_TX; LCD_B4; ARM_LED/TEN; USB_DIR; USB_FS_DM; USB_FS_DP; VSYNC; SPI1_CS; LCD_B5; SPI1_MOSI; LCD_B6; SPI1_CLK; CAN1_TX; HSYNC; LCD_G3; LCD_B7; LCD_CTRL; ADC3_INP0; LAN_TX_EN; TOUCH_MISO; LAN_TXD0; LAN_MDC; LAN_TXD1; LAN_RXERR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

## BANK3 25 IO BANK4 24 IO

## BANK8 6 IO

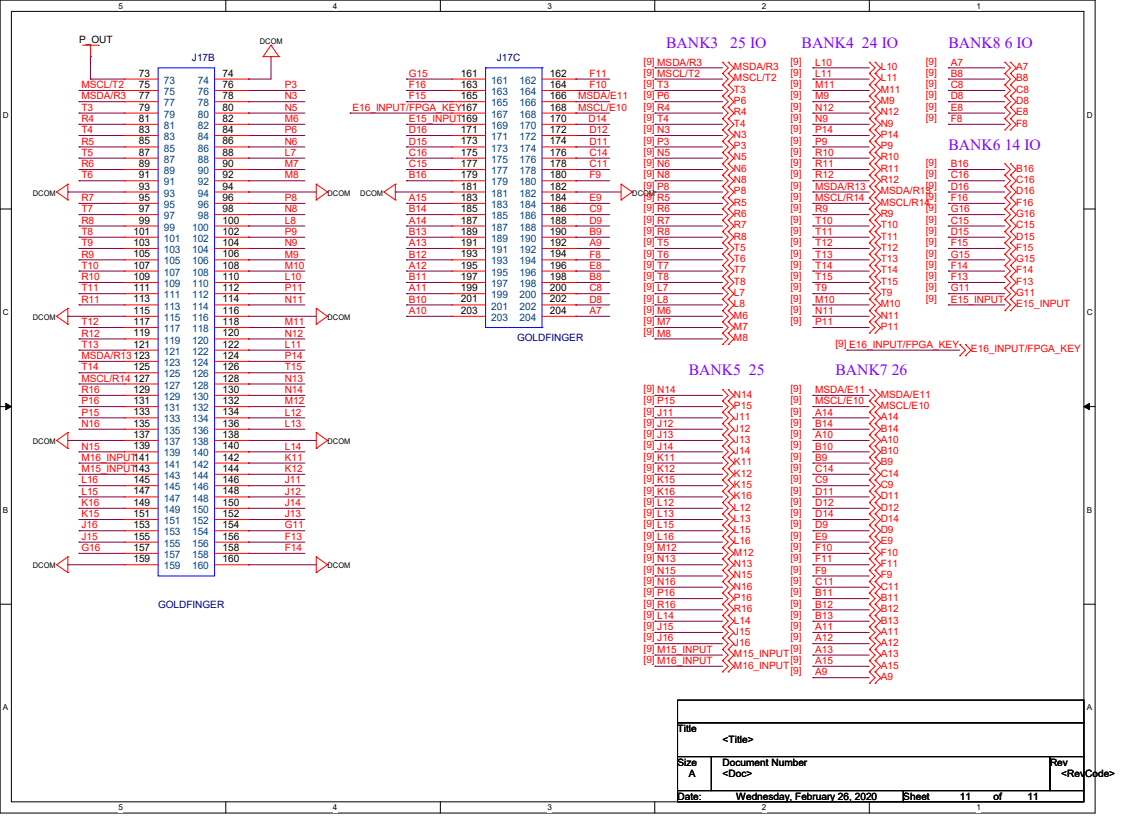
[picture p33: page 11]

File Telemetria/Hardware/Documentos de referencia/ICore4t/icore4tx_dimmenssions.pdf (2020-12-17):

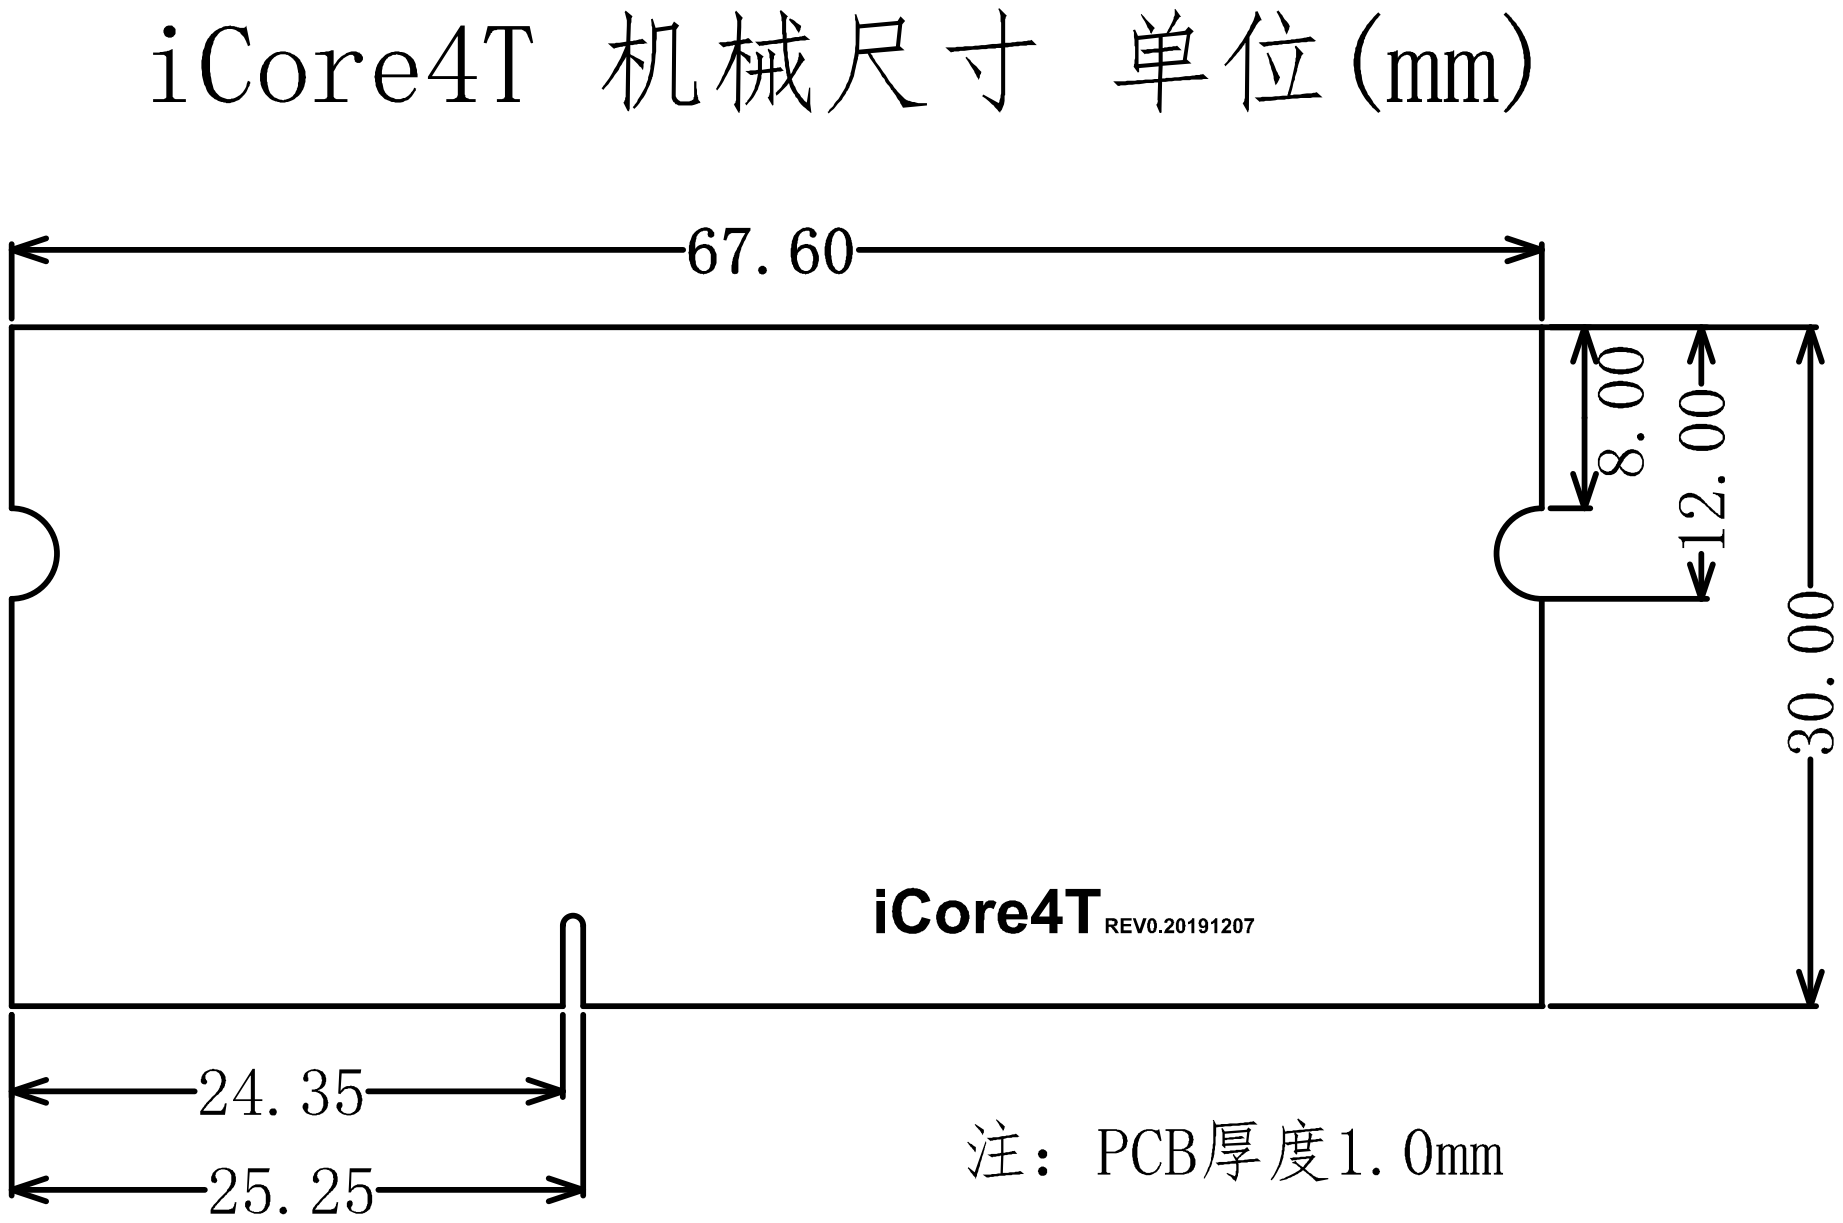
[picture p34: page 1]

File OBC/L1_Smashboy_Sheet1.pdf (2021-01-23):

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


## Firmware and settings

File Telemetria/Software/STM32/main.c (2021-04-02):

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
/* Includes ------------------------------------------------------------------*/
#include "main.h"
#include "cmsis_os.h"

/* USER CODE BEGIN Includes */
#include "SPI_SX.h"
#include "stdio.h"
#include "message_buffer.h"
/* USER CODE END Includes */


CRC_HandleTypeDef hcrc;

I2C_HandleTypeDef hi2c1;
DMA_HandleTypeDef hdma_i2c1_rx;
DMA_HandleTypeDef hdma_i2c1_tx;

SPI_HandleTypeDef hspi1;
SPI_HandleTypeDef hspi3;

TIM_HandleTypeDef htim7;

UART_HandleTypeDef huart1;

osThreadId standbyTaskHandle;
/* USER CODE BEGIN PV */

// ###  FreeRTOS  ###

TaskHandle_t xHandleRadio = NULL;
TaskHandle_t xHandleImage = NULL;
TaskHandle_t xHandleControl = NULL;
TaskHandle_t xHandleDeploy = NULL;
TaskHandle_t xHandleMemory = NULL;
TaskHandle_t xHandleSensor = NULL;

SemaphoreHandle_t xSemBinUART = NULL;
SemaphoreHandle_t xSemBinSPI = NULL;
SemaphoreHandle_t xSemBinI2C = NULL;
SemaphoreHandle_t xSemBinSendImage = NULL;

TimerHandle_t xTimerRTOS;

/* USER CODE END PV */

void SystemClock_Config(void);
static void MX_GPIO_Init(void);
static void MX_DMA_Init(void);
static void MX_CRC_Init(void);
static void MX_SPI1_Init(void);
static void MX_SPI3_Init(void);
static void MX_USART1_UART_Init(void);
static void MX_TIM7_Init(void);
static void MX_I2C1_Init(void);
void StandbyTask(void const * argument);

/* USER CODE BEGIN PFP */

// ###  FreeRTOS  ###

void vTaskRadio( void * pvParameters );
void vTaskImage( void * pvParameters );
void vTaskControl( void * pvParameters );
void vTaskDeploy( void * pvParameters );
void vTaskMemory( void * pvParameters );
void vTaskSensor( void * pvParameters );

void vTimerCallback( TimerHandle_t xTimer );

/* USER CODE END PFP */

/**
  * @brief  The application entry point.
  * @retval int
  */
int main(void)
{
  /* MCU Configuration--------------------------------------------------------*/

  /* Reset of all peripherals, Initializes the Flash interface and the Systick. */
  HAL_Init();

  /* Configure the system clock */
  SystemClock_Config();

  /* USER CODE BEGIN SysInit */

//  vTraceEnable(TRC_START);

  /* USER CODE END SysInit */

  /* Initialize all configured peripherals */
  MX_GPIO_Init();
  MX_DMA_Init();
  MX_CRC_Init();
  MX_SPI1_Init();
  MX_SPI3_Init();
  MX_USART1_UART_Init();
  MX_TIM7_Init();
  MX_I2C1_Init();
  /* USER CODE BEGIN 2 */
  // -----------------------------------------------------------------------------
  // -----------------------------------------------------------------------------

  BaseType_t xReturned;


  // -----------------------------------------------------------------------------
  /* Task Transmitter, equivalente a task 1 do modelo,
   *  esta task configura o radio e transmite os dados
   *  periodicamente */

  xReturned = xTaskCreate(
                  vTaskRadio,       		/* Function that implements the task. */
                  "Radio",    				/* Text name for the task. */
                  256,      				/* Stack size in words, not bytes. */
                  ( void * ) 1,    			/* Parameter passed into the task. */
				  ( ( UBaseType_t ) 1U ),	/* Priority at which the task is created. */
                  &xHandleRadio );    /* Used to pass out the created task's handle. */

  if( xReturned != pdPASS )
  {
	  //  # IMPLEMENTAR TRATAMENTO DE ERRO #
	  configASSERT(0);
  }
  // -----------------------------------------------------------------------------
    /* Task Image, equivalente a task 2 do modelo,
     *  esta task faz a aquisição de um pedaço da
     *  imagem capturada pelo Raspberry */

    xReturned = xTaskCreate(				/* Create the task, storing the handle. */
                    vTaskImage,       		/* Function that implements the task. */
                    "Image",    			/* Text name for the task. */
                    128,      				/* Stack size in words, not bytes. */
                    ( void * ) 1,    		/* Parameter passed into the task. */
  				  ( ( UBaseType_t ) 2U ),	/* Priority at which the task is created. */
                    &xHandleImage );   /* Used to pass out the created task's handle. */

    if( xReturned != pdPASS )
    {
  	  //  # IMPLEMENTAR TRATAMENTO DE ERRO #
  	  configASSERT(0);
    }
    // -----------------------------------------------------------------------------
    xReturned = xTaskCreate(
                    vTaskControl,       	/* Function that implements the task. */
                    "Control",    				/* Text name for the task. */
                    120,      				/* Stack size in words, not bytes. */
                    ( void * ) 1,    			/* Parameter passed into the task. */
  				  ( ( UBaseType_t ) 3U ),	/* Priority at which the task is created. */
                    &xHandleControl );    /* Used to pass out the created task's handle. */

    if( xReturned != pdPASS )
    {
  	  //  # IMPLEMENTAR TRATAMENTO DE ERRO #
  	  configASSERT(0);
    }
    // -----------------------------------------------------------------------------
    /* Task Deploy, equivalente a task 4 do modelo,
     *  esta task realiza o deploy da antena e em
     *  seguida retorna um feedback para task 1   */

    xReturned = xTaskCreate(
                    vTaskDeploy,       		/* Function that implements the task. */
                    "Deploy",    				/* Text name for the task. */
                    64,      					/* Stack size in words, not bytes. */
                    ( void * ) 1,    			/* Parameter passed into the task. */
  				  ( ( UBaseType_t ) 4U ),	/* Priority at which the task is created. */
                    &xHandleDeploy );    		/* Used to pass out the created task's handle. */

      if( xReturned != pdPASS )
      {
      	//  # IMPLEMENTAR TRATAMENTO DE ERRO #
      	configASSERT(0);
      }
      // -----------------------------------------------------------------------------
      /* */

      xReturned = xTaskCreate(
                      vTaskMemory,       		/* Function that implements the task. */
                      "Memory",    				/* Text name for the task. */
                      64,      				/* Stack size in words, not bytes. */
                      ( void * ) 1,    			/* Parameter passed into the task. */
    				  ( ( UBaseType_t ) 2U ),	/* Priority at which the task is created. */
                      &xHandleMemory );    /* Used to pass out the created task's handle. */

      if( xReturned != pdPASS )
      {
    	  //  # IMPLEMENTAR TRATAMENTO DE ERRO #
    	  configASSERT(0);
      }
      // -----------------------------------------------------------------------------
      /* Task Transmitter, equivalente a task 1 do modelo,
       *  esta task configura o radio e transmite os dados
       *  periodicamente */

      xReturned = xTaskCreate(
                      vTaskSensor,       		/* Function that implements the task. */
                      "Sensor",    				/* Text name for the task. */
                      64,      				/* Stack size in words, not bytes. */
                      ( void * ) 1,    			/* Parameter passed into the task. */
    				  ( ( UBaseType_t ) 4U ),	/* Priority at which the task is created. */
                      &xHandleSensor );    /* Used to pass out the created task's handle. */

      if( xReturned != pdPASS )
      {
    	  //  # IMPLEMENTAR TRATAMENTO DE ERRO #
    	  configASSERT(0);
      }
      // -----------------------------------------------------------------------------

    // -----------------------------------------------------------------------------
    // -----------------------------------------------------------------------------

  /* USER CODE END 2 */

  /* USER CODE BEGIN RTOS_MUTEX */
  /* add mutexes, ... */
  /* USER CODE END RTOS_MUTEX */

  /* USER CODE BEGIN RTOS_SEMAPHORES */
  /* add semaphores, ... */
  /* USER CODE END RTOS_SEMAPHORES */

  /* USER CODE BEGIN RTOS_TIMERS */
  /* start timers, add new ones, ... */
  /* USER CODE END RTOS_TIMERS */

  /* USER CODE BEGIN RTOS_QUEUES */
  /* add queues, ... */
  /* USER CODE END RTOS_QUEUES */

  /* Create the thread(s) */
  /* definition and creation of standbyTask */
  osThreadDef(standbyTask, StandbyTask, osPriorityIdle, 0, 64);
  standbyTaskHandle = osThreadCreate(osThread(standbyTask), NULL);

  /* Start scheduler */
  osKernelStart();

  /* We should never get here as control is now taken by the scheduler */
  /* Infinite loop */
  /* USER CODE BEGIN WHILE */
  while (1)
  {
    /* USER CODE END WHILE */

    /* USER CODE BEGIN 3 */
  }
  /* USER CODE END 3 */
}

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
/* USER CODE BEGIN 4 */

// ---------------------------------------------------------------------------------------------
// ---------------------------------------------------------------------------------------------

void HAL_SPI_ErrorCallback (SPI_HandleTypeDef * hspi)
{

}

void HAL_SPI_AbortCpltCallback (SPI_HandleTypeDef * hspi)
{
	static BaseType_t xHigherPriorityTaskWoken;
	xHigherPriorityTaskWoken = pdFALSE;
	xTaskNotifyFromISR(xHandleImage, 0x01, eSetValueWithOverwrite, &xHigherPriorityTaskWoken);
	portYIELD_FROM_ISR(xHigherPriorityTaskWoken);
}

void HAL_UART_ErrorCallback (UART_HandleTypeDef * huart)
{

}

void HAL_UART_AbortReceiveCpltCallback (UART_HandleTypeDef * huart)
{
	static BaseType_t xHigherPriorityTaskWoken;
	xHigherPriorityTaskWoken = pdFALSE;
	xTaskNotifyFromISR(xHandleImage, 0x01, eSetValueWithOverwrite, &xHigherPriorityTaskWoken);
	portYIELD_FROM_ISR(xHigherPriorityTaskWoken);
}

void HAL_SPI_RxCpltCallback (SPI_HandleTypeDef * hspi)
{
	static BaseType_t xHigherPriorityTaskWoken;
	xHigherPriorityTaskWoken = pdFALSE;

	xSemaphoreGiveFromISR(xSemBinSPI, &xHigherPriorityTaskWoken);

	portYIELD_FROM_ISR(xHigherPriorityTaskWoken);
}

void HAL_UART_RxCpltCallback (UART_HandleTypeDef * huart)
{
	static BaseType_t xHigherPriorityTaskWoken;
	xHigherPriorityTaskWoken = pdFALSE;

	xSemaphoreGiveFromISR(xSemBinUART, &xHigherPriorityTaskWoken);

	portYIELD_FROM_ISR(xHigherPriorityTaskWoken);
}


/* Struct feedback é a forma padronizada que as tasks vão informar um feedback para a GS */
typedef struct
{
	uint8_t ID_Task[2];					// ID ou TAG para associar a task
	volatile uint8_t parameter[3];		// Parametro a ser passado como feedback
} feedback;

feedback FbImg, FbCtrl, FbDpl, FbMmry, FbSensor, FbRadio;

uint8_t ADCS_Buffer_Transmit[25];
uint8_t ADCS_Buffer_Receive[25];

// Status Task Deploy
#define FOLDED  		0x0
#define DEPLOYING  		0x1
#define NOT_DEPLOYED  	0x2
#define FULLY_DEPLOYED  0x3

// RPi Task Image
#define CONFIG		0x00
#define FINISH		0xFF
#define SUSPEND		0x55
#define PICTURE		0x0F
#define SEND		0xC3
#define CONTINUE	0xA5
#define SHUTDOWN	0xF4

uint8_t *pBufferSPI = NULL;
_Bool imgFinishFlag = 0;

#define ADDR_BNO	0x29

// ---------------------------------------------------------------------------------------------
// ---------------------------------------------------------------------------------------------

void HAL_GPIO_EXTI_Callback (uint16_t GPIO_Pin)
{
	/* Usado em caso de necessidade de mudança de contexto entre as tasks */
	static BaseType_t xHigherPriorityTaskWoken;
	xHigherPriorityTaskWoken = pdFALSE;

	switch (GPIO_Pin) {
		case Fdb_Deploy_Pin:
			HAL_GPIO_WritePin(LED_GPIO_Port, LED_Pin, GPIO_PIN_RESET);										// Desativa elemento de aquecimento
			xTaskNotifyFromISR(xHandleDeploy, FULLY_DEPLOYED, eSetValueWithOverwrite, &xHigherPriorityTaskWoken);		// Informa Task Deploy
			break;

		case DIO1_Pin:
			/* Interrupção TX DONE */
			SX_ClearIrqStatus(0x01);											// Limpa flags
			HAL_GPIO_WritePin(TXEN_GPIO_Port, TXEN_Pin, GPIO_PIN_RESET);		// Desativa o amplificador de RF (TX) para poupar (MUITA) energia

			xTaskNotifyFromISR(xHandleRadio, 0x06, eSetValueWithOverwrite, &xHigherPriorityTaskWoken);		// Informa Task Radio, via Notificacao
			break;

		case DIO2_Pin:
			/* Interrupção RX DONE */
			SX_ClearIrqStatus(0x02);											// Limpa flags
			HAL_GPIO_WritePin(RXEN_GPIO_Port, RXEN_Pin, GPIO_PIN_RESET);		// Desativa o amplificador de RF (RX) para poupar energia

			xTaskNotifyFromISR(xHandleRadio, 0x09, eSetValueWithOverwrite, &xHigherPriorityTaskWoken);		// Informa Task Radio, via Notificacao
			break;
	}

	/* Macro que verifica necessidade de mudança de contexto entre as tasks */
	portYIELD_FROM_ISR( xHigherPriorityTaskWoken );
}

// ---------------------------------------------------------------------------------------------
// ---------------------------------------------------------------------------------------------

void vTaskRadio( void * pvParameters )
{
	// Desenvolvimento
	static UBaseType_t uxHighWaterMarkRadio;
	uxHighWaterMarkRadio = uxTaskGetStackHighWaterMark( NULL );

	// Feedback
	FbRadio.ID_Task[0] = 'R';	FbRadio.ID_Task[1] = 'D';
	FbRadio.parameter[0] = ' ';	FbRadio.parameter[1] = ' ';	FbRadio.parameter[2] = ' ';

	/* Array de ponteiros que armazena todos os endereços das variaveis de feedbacks */
	feedback *pArrayFeedback[] = {&FbDpl, &FbImg, &FbRadio, &FbCtrl, &FbSensor, &FbMmry};

	// State Machine
	enum {suspend, receive, transmit, screening};
	uint8_t state = receive;

	// Task Notify
	uint32_t radioFeedback = 0;

	// Radio RX
	uint8_t status, PayloadLengthRx, RxStartBufferPointer;
	uint8_t *pRadioBuffer = NULL;

	// Radio TX
	uint8_t payload[255];
	uint16_t contador = 0;
	for(int i = 0; i < sizeof(payload); i++)	payload[i] = 0x00;		// zera a memoria, mensagem de feedback
	uint8_t resto = 0, ultimo = 0;

	// Image
	_Bool flag_metadada = 0;
	uint8_t metadata[6], message_repeat[9];
	uint16_t ID, size;

	//-----------------------------------------------------------------------------------------------------------------

	// -=-=-=-=-=-=-=-=- TIMER_5 SETUP -=-=-=-=-=-=-=-=-
	// Este timer serve para dar tempo ao BUSY, especificado em datasheet, pag 52, Tsw.
	// Está configurado para operar com 480MHz no clock principal, 240MHz em APB1_Timer_clock

	// Timer configurado em 400n para clock de 240MHz, o resultado final considera o tempo do timer + o atraso do codigo
//	TIM7->PSC = 0x04;		// Clock prescaler
//	TIM7->ARR = 23;			// Auto-reload register

	TIM7->SR = 0x00;		// Clear Flag Interrupt
	TIM7->DIER |= 0x01;		// Update interrupt enable

	//-----------------------------------------------------------------------------------------------------------------

	/* -=-=-=-=-=-=-=-=- RADIO SETUP -=-=-=-=-=-=-=-=- */

	uint8_t LoRaSyncWord[2] = { 0x14, 0x24 };							// Sync Word Lora

	HAL_GPIO_WritePin(NRST_GPIO_Port, NRST_Pin, GPIO_PIN_SET);			// Habilita o rádio
	HAL_GPIO_WritePin(TXEN_GPIO_Port, TXEN_Pin, GPIO_PIN_RESET);		// Desativa o amplificador de RF (TX) para poupar (MUITA) energia
	HAL_GPIO_WritePin(RXEN_GPIO_Port, RXEN_Pin, GPIO_PIN_RESET);		// Desativa o amplificador de RF (RX) para poupar energia

	osDelay(50);														// Aguarda um tempinho para estabilização do radio

	SX_SetStandby(0x00);												// Modo Standby para poder realizar as configurações iniciais

	/* Rotinas de calibração */
	SX_ClearDeviceErrors();
	SX_SetDIO3AsTCXOCtrl(0x07, 0x32);
	SX_CalibrateFunction(0x7F);
	SX_CalibrateImage();

	/* Deve tratar erros de calibração caso existam*/
	switch (SX_GetDeviceErrors())
	{
		case 0x01:

			break;
		default:
			break;
	}

	/* Setup do rádio */					//  #### Para ficar mais intuitivo, utilizar #defines    ####
	SX_SetPacketType(0x01);
	SX_SetFrequency(915e6);
	SX_SetPaConfig(0x04, 0x07, 0x00);		// Afeta a potencia de saida	0x04 0x07 0x00 MAX
	SX_SetTxParam(4, 0x03);					// Afeta a potencia de saida	22 MAX
	SX_SetBufferBaseAddress(0x7F, 0x00);
	SX_SetModulationParamsLoRa(0x07, 0x04, 0x01, 0x00);
	SX_WriteRegister(0x0740, LoRaSyncWord, 2);
//----------------------------------------------------------------------------------------------------------------------------------
										/* -=-=-=-=-=-=-=-=- LOOP RADIO -=-=-=-=-=-=-=-=- */
	for(;;)
	{
		switch (state)
		{
			case suspend:
				if( xTaskNotifyWait(0x00, 0xFFFFFFFF, &radioFeedback, 2000) == pdTRUE)		// Notificado via interrupcao externa
				{
					if( 0x06 == (radioFeedback & 0x0F) )
					{	// Causado pela interrupção TxDone, o procedimento de envio finalizou
						state = receive;
					}
					else if( 0x09 == (radioFeedback & 0x0F) )
					{	// Causado pela interrupção RxDone, algo foi recebido
						state = screening;
					}
					else if( 0x0B == (radioFeedback & 0x0F) )
					{	// Aviso da Task Image informando que está pronta para transmitir
						HAL_GPIO_WritePin(RXEN_GPIO_Port, RXEN_Pin, GPIO_PIN_RESET);		// Desativa o amplificador de RF (RX) para poupar energia
						state = transmit;
					}
				}
				else
				{	// Timeout, o radio não gerou interrupção, transmite telemetria
					HAL_GPIO_WritePin(RXEN_GPIO_Port, RXEN_Pin, GPIO_PIN_RESET);			// Desativa o amplificador de RF (RX) para poupar energia
					state = transmit;														// ########>>>>>>>>>>>>>>> DESCOMENTAR PARA VOLTAR A TRANSMITIR <<<<<<<<<<<<<<<<<<<##############

					uxHighWaterMarkRadio = uxTaskGetStackHighWaterMark( NULL );				// Remover isso daqui futuramente, está aqui para analise ##################
				}
				break;
//----------------------------------------------------------------------------------------------------------------------------------
			case receive:
				SX_SetDioIrqParams(0x02, 0, 0x02, 0);										// Configura interrupção RX Done
				SX_RX(0);																	// Coloca o rádio em RX Mode
				state = suspend;
				break;
//----------------------------------------------------------------------------------------------------------------------------------
			case transmit:					//		=-=-=-=-=  IMAGEM  =-=-=-=-=
				if(xSemaphoreTake(xSemBinSendImage, 0) == pdTRUE)							// Semaforo relacionado com o envio da imagem
				{
					if(flag_metadada)		//	    - - - --  Metadados  -- - - - 			// Flag para realizar aquisição do metadado uma única vez
					{
						flag_metadada = 0;													// clear flag

						metadata[0] = 0x50;					// HEADER						// Codigo de identificação
						metadata[1] = 0x4D;					// HEADER						// Tipo de dado
						metadata[2] = *(pBufferSPI + 4052);	// PAYLOAD
						metadata[3] = *(pBufferSPI + 4053);	// PAYLOAD
						metadata[4] = *(pBufferSPI + 4054);	// PAYLOAD
						metadata[5] = *(pBufferSPI + 4055);	// PAYLOAD

						SX_SetStandby(0x00);												// Inicia processo de transmissão
						SX_SetPacketParamsLoRa(0x08, 0x00, sizeof(metadata), 0x01, 0x00);	// Define parametros da transmissão
						SX_SetDioIrqParams(0x01, 0x01, 0, 0);								// Define interrupção
						SX_SetBufferBaseAddress(0x00, 0x00);								// Define endereços no FIFO do Rádio
						SX_WriteBuffer(0x00, metadata, sizeof(metadata));					// Escreve Buffer
						SX_TX(0);															// Transmite
					}
					else					//	      - - - --  Imagem  -- - - -
					{	// verdadeiro na primeira vez que entrar aqui, em caso de solicitacao de reenvio, isso sera falso
						if(!(message_repeat[0] & 0x80))
						{
							size = *(pBufferSPI + 2) << 8 | *(pBufferSPI + 3);				// 'size' recebe o tamanho do pacote, normalmente é 4048 e o ultimo costuma ser menor
							message_repeat[0] = 0x80 | (size/253);							// 'message_repeat' informa quantas mensagens são necessários transmitir (ou repetir em caso de solicitaçao de reenvio)
																							//     se for o primeiro envio, "repita todas" (equivale a enviar todas), se for uma solicitação de retransmissão, retransmite apenas a quantidade solicitada
							resto = size % 253;
							if(resto)														// Normalmente o ultimo pacote não tem tamanho multiplo de 253, então vai sobrar um 'resto' de bytes para ser transmitidos
							{
								ultimo = message_repeat[0] & 0x1F;							// o ultimo(indice) pacote vai ter um tratamento especial pra não ser transmitido lixo de memória, o tamanho dele vai ser menor que 253 (255) bytes
								message_repeat[0]++;										// soma 1 pra poder transmitir os bytes restantes
							}
							else
								ultimo = 255;												// só um numero grande pra exessao não ocorrer quando não deve

							ID = *(pBufferSPI + 0) << 8 | *(pBufferSPI + 1);				// ID decrescente que informa quantos pacotes de 4048 ainda faltam
							FbImg.parameter[0] = 'I'; FbImg.parameter[1] = 'D'; FbImg.parameter[2] = 0x30 | (0xF & ID);

							if(ID == 0)
								imgFinishFlag = 1;
							else
								imgFinishFlag = 0;
						}

						*(pBufferSPI + 4058) = 0x50;	// Codigo de identificação			// HEADER		Reaproveita o espaço já alocado pra não precisar alocar mais um pedaço
//					- - - - - - - - - - - - - - - - - - - - - - - - - - - - - - - - - - - - -

						for(int i = 0; i < (message_repeat[0] & 0x1F); i++)
						{
							if(i%2 == 0)													// HEADER		// Logica que separa 1 byte em 2 numeros
								*(pBufferSPI + 4059) = ( 0x40 | (message_repeat[1 + (i/2)] >> 4) );			// Os pacotes a serem transmitidos chegam agrupados de 2 em 2 para cada byte de 'message_repeat[1~9]'
							else																			//   essa lógica separa esses números para que possam ser transmitidos corretamente
								*(pBufferSPI + 4059) = 0x40 | (message_repeat[1 + (i/2)] & 0x0F);

							SX_SetStandby(0x00);											// Inicia procedimento de transmissão

							if( (*(pBufferSPI + 4059) & 0x0F) == ultimo)					// (*(pBufferSPI + 4059) & 0x0F) é o indice da transmissão, no dado transmitido corresponde ao 'n' em '0x4n'
								SX_SetPacketParamsLoRa(0x08, 0x00, resto+2, 0x01, 0x00);	// se for o ultimo pacote, e ele for menor que 253, essa lógica garante que não será transmitido lixo de momória
							else
								SX_SetPacketParamsLoRa(0x08, 0x00, 255, 0x01, 0x00);		// em casos normais, o pacote terá o tamanho máximo

							SX_SetDioIrqParams(0x01, 0x01, 0, 0);
							SX_SetBufferBaseAddress(0x00, 0x00);
							SX_WriteBuffer(0x00, (pBufferSPI + 4058), 2);					// HEADER
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

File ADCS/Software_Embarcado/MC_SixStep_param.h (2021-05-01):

/**
 ******************************************************************************
 * @file    MC_SixStep_param.h
 * @author  System lab - Automation and Motion control team
 * @version V1.0.0
 * @date    06-July-2015
 * @brief   This header file provides all parameters to driver a motor with 6Step
            library
 ******************************************************************************
 * @attention
 *
 * <h2><center>&copy; COPYRIGHT(c) 2015 STMicroelectronics</center></h2>
 *
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
 ******************************************************************************
 */

/** @addtogroup MIDDLEWARES     MIDDLEWARES 
  * @brief  Middlewares Layer
  * @{ 
*/

/** @addtogroup MC_6-STEP_LIB       MC_6-STEP_LIB 
  * @brief  Motor Control driver
  * @{ 
*/

/** @defgroup Main_Motor_parameters    Main_Motor_parameters
  *  @{
    * @brief All motor parameters for 6Step driving
*/
 
/* **************************************************************************** 
 ==============================================================================   
                       ###### BASIC PARAMETERS ######
 ============================================================================== 
**************************************************************************** */   
#define NUM_POLE_PAIRS                       7      /*!< Number of Motor Pole pairs */
#define DIRECTION                            0      /*!< Set motor direction CW = 0 and CCW = 1*/
#define TARGET_SPEED                       200      /*!< Target speed in closed loop control */
#define POTENTIOMETER                        0      /*!< Enable (1)/Disable (0) the potentiometer */


/* **************************************************************************** 
 ==============================================================================   
                       ###### ADVANCED PARAMETERS ######
 ============================================================================== 
**************************************************************************** */  
/*!< ********************* Open loop control *********************************/
#define STARTUP_CURRENT_REFERENCE         100      /*!< StartUP Currente Reference (2000 = 2.2A)*/
#define ACC                                500      /*!< Mechanical acceleration rate (setting available in manual mode, LOAD_TYPE = 0) */
#define MINIMUM_ACC                        500      /*!< Mechanical acceleration rate for BIG load application */ 
#define NUMBER_OF_STEPS                  20000      /*!< Number of elements for motor start-UP (max value 65535)*/
#define TIME_FOR_ALIGN                    1200      /*!< Time for alignment (msec)*/
#define BUTTON_DELAY                      1000      /*!< Delay time to enable push button for new command (1 = 1msec)*/ 
#define NUMBER_ZCR                          12      /*!< Number of zero crossing event during the startup for closed loop control begin */   
/*!< ********************* Closed Loop control *********************************/
#define SPEED_LOOP_TIME                      1      /*!< Speed Loop time (1 = 1msec) */
#define KP_GAIN                             50      /*!< Kp parameter for PI regulator */
#define KI_GAIN                            400      /*!< Ki parameter for PI regulator */
#define KP_DIV                             200      /*!< Kp parameter divider for PI regulator */
#define KI_DIV                             200      /*!< Ki parameter divider for PI regulator */
#define LOWER_OUT_LIMIT                    -8      /*!< Low Out value of PI regulator */
#define UPPER_OUT_LIMIT                     8      /*!< High Out value of PI regulator */
#define MAX_POT_SPEED                    15000      /*!< Maximum Speed regulated by potentiometer */
#define MIN_POT_SPEED                     1000      /*!< Minimum Speed regulated by potentiometer */
#define VAL_POT_SPEED_DIV                    2      /*!< Validation potentiometer speed divider */
#define INITIAL_DEMAGN_DELAY                10      /*!< Initial value for delay time during startup for Bemf detection */

/*!< Zero Crossissing parameters */
#define BEMF_THRSLD_DOWN                    100     /*!< Zero Crossing threshold */
#define BEMF_THRSLD_UP                      70     /*!< Zero Crossing threshold */

/*!< Speed filtering parameters */
#define FILTER_DEEP                         20      /*!< Number of bits for digital filter */  
#define HFBUFFERSIZE                        10
#define ADC_SPEED_TH                        82      /*!<Fixed treshold to change the target speed (t.b.f) */ 

/*!< Motor stall detection parameters */
#define BEMF_CONSEC_DOWN_MAX               100     /*!< Maximum value of BEMF Consecutive Threshold Falling Crossings Counter in closed loop */
#define BEMF_CNT_EVENT_MAX                 100     /*!< Maximum number of BEMF Counter in open loop*/
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

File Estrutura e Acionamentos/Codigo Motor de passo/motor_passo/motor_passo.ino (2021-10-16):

#include <Stepper.h>

int stepsPerRevolution = 800;  // Aqui configurei micropassos 1/4 --- 
                               //precisa de 800 micropassos para uma revolução no Nema 16 Unipolar

const int fimdeCurso1 = 2;  // porta 2 do Arduino UNO
const int fimdeCurso2 = 5;  // porta 5 do Arduino UNO
const int pinoLedAzul = 3;
const int pinoLedVerde = 4;

bool volta = false;


// inicializa a biblioteca criando uma instancia do motor
Stepper myStepper(stepsPerRevolution, 8, 9); 

void setup() {
  pinMode(fimdeCurso1,INPUT_PULLUP);
  pinMode(fimdeCurso2,INPUT_PULLUP);
  pinMode(pinoLedAzul, OUTPUT); //DEFINE O PINO COMO SAÍDA
  pinMode(pinoLedVerde, OUTPUT); //DEFINE O PINO COMO SAÍDA
  
  myStepper.setSpeed(800); // ajusta a velocidade inicial para 800 passos
}

void loop() {
 
  stepsPerRevolution = 800;

  // faz a leitura do fim de curso
  
  if (digitalRead(fimdeCurso1) == HIGH && volta == false) {
          delay(1);
          digitalWrite(pinoLedAzul, HIGH); //ACENDE O LED
          digitalWrite(pinoLedVerde, LOW); //APAGA O LED
          myStepper.setSpeed(100); // ajusta a velocidade inicial para 100 passos
          myStepper.step(-stepsPerRevolution);
   } 
   
   if (digitalRead(fimdeCurso1) == LOW && volta == false) {
          myStepper.setSpeed(2); // ajusta a velocidade inicial para 2 passos 
          digitalWrite(pinoLedAzul, LOW); //APAGA O LED
          digitalWrite(pinoLedVerde, HIGH); //ACENDE O LED
          
          delay(2000); //PAUSA DE 2 SEGUNDOS
          volta = true;
    }

    if( volta == true){
       digitalWrite(pinoLedVerde, HIGH); //ACENDE O LED
       myStepper.setSpeed(200); // ajusta a velocidade inicial para 200 passos
       myStepper.step(stepsPerRevolution);   
    }

    if (digitalRead(fimdeCurso2) == HIGH && volta == true) {
          myStepper.setSpeed(2); // ajusta a velocidade inicial para 2 passos
          digitalWrite(pinoLedAzul, HIGH); //ACENDE O LED
          digitalWrite(pinoLedVerde, LOW); //APAGA O LED
          
          delay(2000); //PAUSA DE 2 SEGUNDOS
          volta = false;
    }
}

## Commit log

2020-08-22 Add files via upload
    Remove Before Flight Pin ; É utilizado para manter o satelite desligado ate o momento do lançamento.
2020-08-22 Add files via upload
    É utilizada para a separação dos satelites apos o lançamento.
2020-08-22 Add files via upload
    Switches utilizados como deployment switch.
2020-08-22 Add files via upload
    Versões dos trilhos utilizados no projeto
    [trilho-deploy-switch.SLDPRT, trilho-separation-spring.SLDPRT]
2020-08-22 Add files via upload
    Estrutura para o possivel uso de controladores VESC para os motores da roda de reação.
2020-09-03 update 2020.09.03.17.00
    adicionado melhoria no sistema de feedback
2020-09-04 update 2020.09.04.08.00
    Adicionado gerenciamento automático de feedback
2020-09-17 Arquivos que foram feitos em maio no RPi ZW
    Arquivos majoritariamente em C
2020-09-24 DESATUALIZADO. Primeira versão do código do Raspberry.
    A primeira versão foi escrita em C, mas depois eu optei por escrever em Python pois desta maneira é mais simples de futuros membros manterem o código, já que python simplifica bastante a vida de quem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
2020-09-29 Add files via upload
    adicionado task de imagem, e chamada segura para ela
2020-10-13 Add files via upload
    Solicitação de reenvio implementada
2020-10-26 Add files via upload
    Arquivos de templates padrão Orion 2020.
2020-12-06 correção de bugs em Image
    [main.c]
2021-01-08 CAD Motor
    [Motor_BLDC_LE2204_KV1800.STEP]
2021-01-23 23012021_beta
    Precisa ser atualizada em breve
    [L1_Smashboy_Sheet1.SchDoc, Orion_L1_SmashBoy.PrjPcb]
2021-01-24 24012021 beta
    Em processo de verificação.
    Impedâncias corrigidas.
    [L1_Smashboy_Sheet1.SchDoc, Orion_L1_SmashBoy.PrjPcb]
2021-01-25 Revisado 25012021
    Upando como backup, o esquemático precisa ser melhor organizado, mas o projeto a principio está concluído
    [ADCS.SchDoc]
2021-01-25 Finalizado, Revisado 250121
    Upando como backup, Incluir as informações de "Autor" no esquemático (template da equipe)
    [TTeC_PCB2.PcbDoc, TTeC_Sheet1.SchDoc]
2021-01-25 Revisado, finalizado 25012021
    Upando como backup, incluir as informações de "Autor" no esquemático
    [L1_Smashboy_Sheet1.SchDoc, Orion_L1_SmashBoy.PrjPcb]
2021-02-05 Sun sensor STEP 3D
2021-02-14 Backup_v0.1 / 3 individuais
    [ADCS_2.SchDoc]
2021-02-15 v15022021 - Finalizado/Revisado
    3 microcontroladores independentes
    [ADCS_2.SchDoc, Orion_ADCS_SmashBoy.PrjPcb]
2021-03-02 Motor e IMU funcionando
2021-04-05 codigo ADCS até o fechamento da sprint 9
    O motor está funcional e a comunicação com a placa OBC através de I2C via DMA está certa. O motor ainda precisa de ajustes no controle de aceleração com a roda acoplada para não travar.
2021-04-05 Código OBC/TLM até o fechamento da sprint 9
    Implementada comunicação com IMU e ADCS via I2C utilizando DMA. Necessário implementar técnicas de tratamento de falhas/ mal funcionamento.
2021-05-01 controle brabo de aceleracao
2021-07-17 SETUP ADCS V2
    [18650.SLDPRT, L1.SLDPRT, L1_v2.SLDPRT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]
2021-08-09 CODIGO
    Todos os códigos de controle utilizado no setup ADCS (SmashLittleBoy) para desenvolvimento do controle de atitude em um eixo

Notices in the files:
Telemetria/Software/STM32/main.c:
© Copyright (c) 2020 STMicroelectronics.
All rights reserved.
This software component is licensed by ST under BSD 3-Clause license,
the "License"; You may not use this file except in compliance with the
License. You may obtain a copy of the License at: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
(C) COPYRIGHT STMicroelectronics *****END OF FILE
